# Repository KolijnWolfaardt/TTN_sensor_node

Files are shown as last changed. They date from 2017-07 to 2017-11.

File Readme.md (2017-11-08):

# TTN Sensor Board

This is a basic sensor board I designed to experiment with the LORAWAN protocol, and [The Things Network](https://www.thethingsnetwork.org/) infrastructure. It is by no means intended to be a good or complete example of all the capabilities of either.

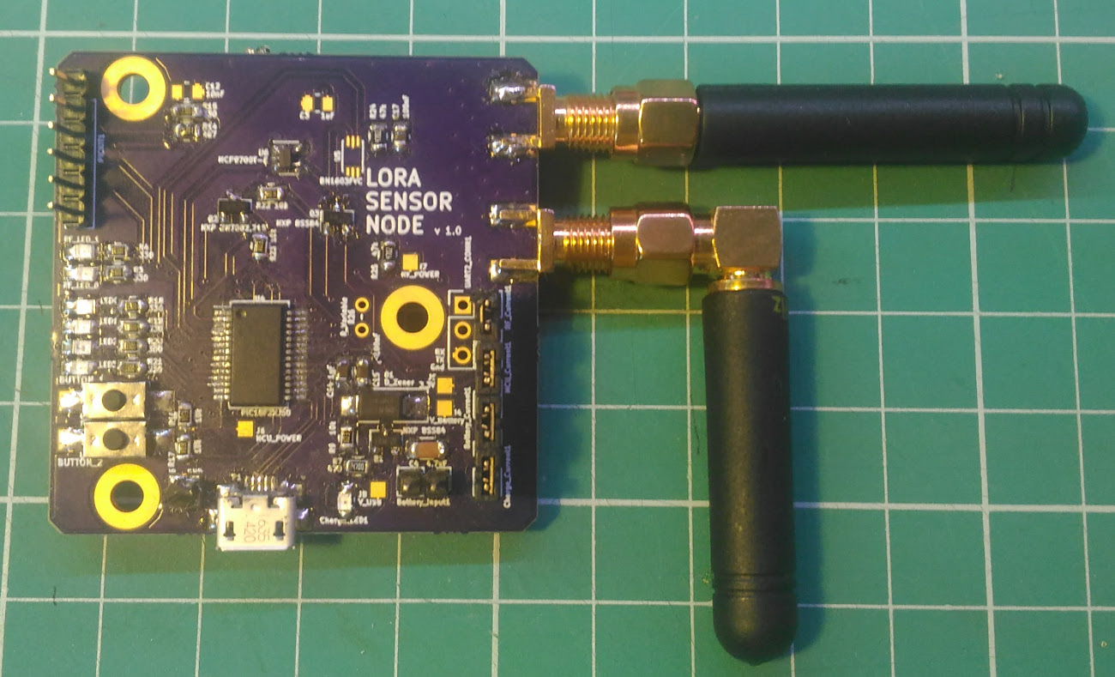
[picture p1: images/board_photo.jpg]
Photo of soldered board


The board uses a Microchip RN2483 to perform the RF communication and a PIC18F46J50 for the other work. The sensors were chosen based on what was available, for experimentation. Other sensors can easily be used.

The board is powered by a single LiPo battery, which is regulated down to 3.3v. To charge the LiPo battery, A MCP73831/2 Battery Management IC is used. The power part is not finished yet, as the batteries have not arrived, so there might be updates here.

## Datasheets
* Microcontroller [PIC18F26J50](http://ww1.microchip.com/downloads/en/DeviceDoc/39931d.pdf)
* Lora Interface module [RN2483](http://ww1.microchip.com/downloads/en/DeviceDoc/50002346A.pdf)
* Battery Management IC [MCP73831/2](http://ww1.microchip.com/downloads/en/DeviceDoc/20001984g.pdf)
* Low dropout Voltage Regulator [TPS736](http://www.ti.com/lit/ds/symlink/tps736.pdf)
* Ambient Light Sensor [BH1603FVC](http://rohmfs.rohm.com/en/products/databook/datasheet/ic/sensor/light/bh1603fvc-e.pdf)
* Thermistor [MCP9701/9701A](http://ww1.microchip.com/downloads/en/DeviceDoc/21942e.pdf)
* P-channel MOSFET [NXP BSS84](http://www.nxp.com/documents/data_sheet/BSS84.pdf)
* N-channel MOSFET [NXP 2N7002](https://www.nxp.com/documents/data_sheet/2N7002.pdf)

Thanks to [https://github.com/jpmeijers/RN2483shield](https://github.com/jpmeijers/RN2483shield) for the RN2483 component and module.

## Schematic and PCB layout
The schematic and PCB layout were created using KiCad, and can be found in the **PCB Layout** folder. The gerber files and schematic PDF can also be found there.

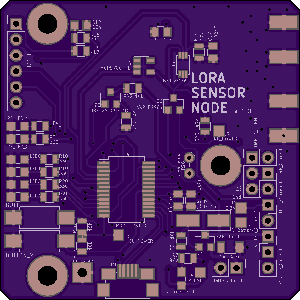
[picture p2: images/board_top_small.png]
Board Top layout
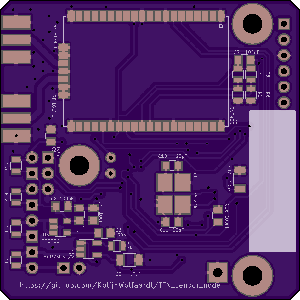
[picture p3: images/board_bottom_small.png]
Board Top layout
  

## Firmware
The firmware can be found in the Firmware folder, and is intended for the [XC8](http://www.microchip.com/mplab/compilers) compiler using the [MPLABX](http://www.microchip.com/mplab/mplab-x-ide) IDE. The board is programmed with a PicKIT 3 programmer, but the PicKIT 2 should also work. The basic flow of the program is shown in basic_control_flow.dia (Open with [http://dia-installer.de/](Dia) flowchart editor) inside the Firmware folder.

[comment]: #  (For more details on the software, see [Firmware/README.md](Firmware/README.md) )

The radio connects via ABP (Activation by personalization). The keys were programmed beforehand using a USB-serial converter, and the radio stores them internally. I will add some code later to set them in the code.

USB stack adapted from [https://github.com/signal11/m-stack.git](https://github.com/signal11/m-stack.git), for its license see the LICENSE file.

[comment]: # (Bill of Materials)

## Board Mistakes
There are two mistakes on the board:
* The ground pin on the PicKit header is not connected.
* The battery voltage measurement circuit does not work. I replaced it with a voltage divider.

These are suggestions that require more rework, but are only for ease of use.
* I cannot identify pin 1 of the optical sensor, so I left it off.
* Breaking out the TX and RX lines to the RF module would have eased debugging.
* A reset button would be nice, resetting both the MCU and the RF module.

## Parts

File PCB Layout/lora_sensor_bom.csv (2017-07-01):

Reference | Quantity | Value | Footprint | Datasheet
BUTTON_1 BUTTON_2 | 2 | SwitchTactile | Buttons_Switches_SMD:SW_SPST_REED_CT05-XXXX-G1
C1 C15 C16 C17 C2 C6 C7 C8 | 8 | 100nF | Capacitors_SMD:C_0805
C10 C11 | 2 | 22pF | Capacitors_SMD:C_0805
C12 | 1 | 10nF | Capacitors_SMD:C_0805
C13 | 1 | 10uF | Capacitors_SMD:C_1206
C14 C3 C9 | 3 | 1uF | Capacitors_SMD:C_0805
C4 C5 | 2 | 4.7uF | Capacitors_SMD:C_1206
D1 | 1 | D_Zener | Diodes_SMD:D_SMA_Handsoldering
J1 J2 J3 | 3 | CONN_01X01 | Mounting_Holes:MountingHole_3.2mm_M3_Pad
J4 | 1 | V_Battery | Measurement_Points:Measurement_Point_Square-SMD-Pad_Small
J5 | 1 | 3.3V | Measurement_Points:Measurement_Point_Square-SMD-Pad_Small
J6 | 1 | MCU_POWER | Measurement_Points:Measurement_Point_Square-SMD-Pad_Small
J7 | 1 | RF_POWER | Measurement_Points:Measurement_Point_Square-SMD-Pad_Small
J8 | 1 | V_USB | Measurement_Points:Measurement_Point_Square-SMD-Pad_Small
J9 | 1 | GND | Measurement_Points:Measurement_Point_Square-TH_Big
Battery_Current1 Battery_Input1 Charge_Current1 MCU_Current1 RF_Current1 | 5 | CONN_01X02 | Pin_Headers:Pin_Header_Straight_1x02_Pitch2.54mm
P1 | 1 | USB_A | libraries:USB_Micro
PICKIT1 | 1 | CONN_01X06 | Pin_Headers:Pin_Header_Straight_1x06_Pitch2.54mm
Q1 Q3 | 2 | NXP BSS84 | TO_SOT_Packages_SMD:SOT-23
Q2 | 1 | NXP 2N7002,215 | TO_SOT_Packages_SMD:SOT-23
R10 | 1 | 2k | Resistors_SMD:R_0805
R14 | 1 | 4k7 | Resistors_SMD:R_0805
R24 R25 | 2 | 47k | Resistors_SMD:R_0805
R26 | 1 | R_Variable | Resistors_ThroughHole:R_Axial_DIN0204_L3.6mm_D1.6mm_P2.54mm_Vertical
R15 R18 R19 R20 R21 R3 R4 | 7 | 330 | Resistors_SMD:R_0805
R1 R11 R12 R13 R2 R5 R6 R8 | 8 | 0 | Resistors_SMD:R_0805
R7 | 1 | 470 | Resistors_SMD:R_0805
R16 R17 R22 R23 R9 | 5 | 10k | Resistors_SMD:R_0805
RF_HIGH_1 RF_LOW_1 | 2 | CONN_01X02 | libraries:SMA_edge_connect
LED0 LED1 LED2 LED3 Power_LED1 RF_LED_0 RF_LED_1 | 7 | LED | LEDs:LED_0805
U1 | 1 | RN2483 | libraries:RN2483
U2 | 1 | MCP73831/2 | TO_SOT_Packages_SMD:TSOT-23-5
U3 | 1 | TPS736 | TO_SOT_Packages_SMD:SOT-23-5
U4 | 1 | PIC18F2XJ50 | Housings_SSOP:SSOP-28_5.3x10.2mm_Pitch0.65mm
U5 | 1 | BH1603FVC | libraries:BH1603FVC
U6 | 1 | MCP9700T-E | TO_SOT_Packages_SMD:SOT-23-5
UART2_CONN1 | 1 | CONN_01X03 | Pin_Headers:Pin_Header_Straight_1x03_Pitch2.54mm
Y1 | 1 | FA_238 | libraries:Crystal_FA-238

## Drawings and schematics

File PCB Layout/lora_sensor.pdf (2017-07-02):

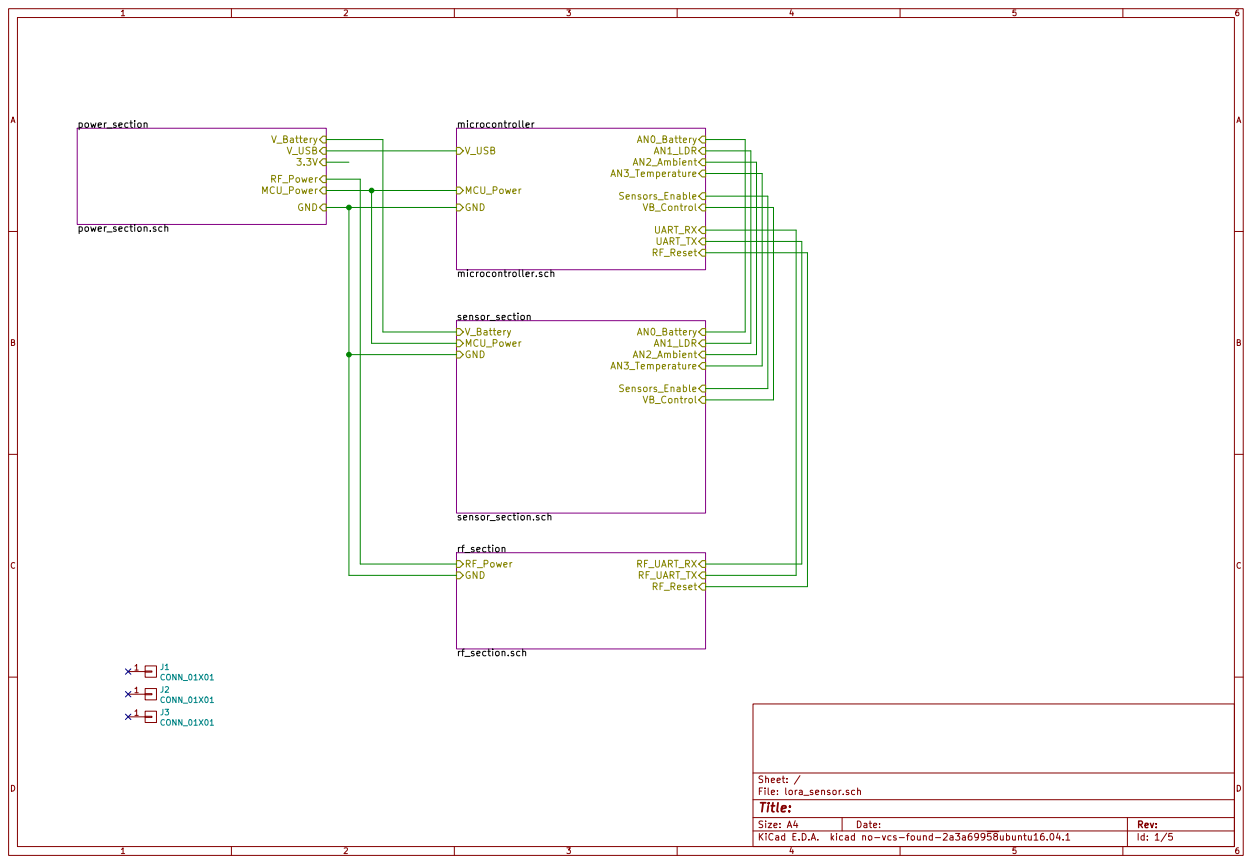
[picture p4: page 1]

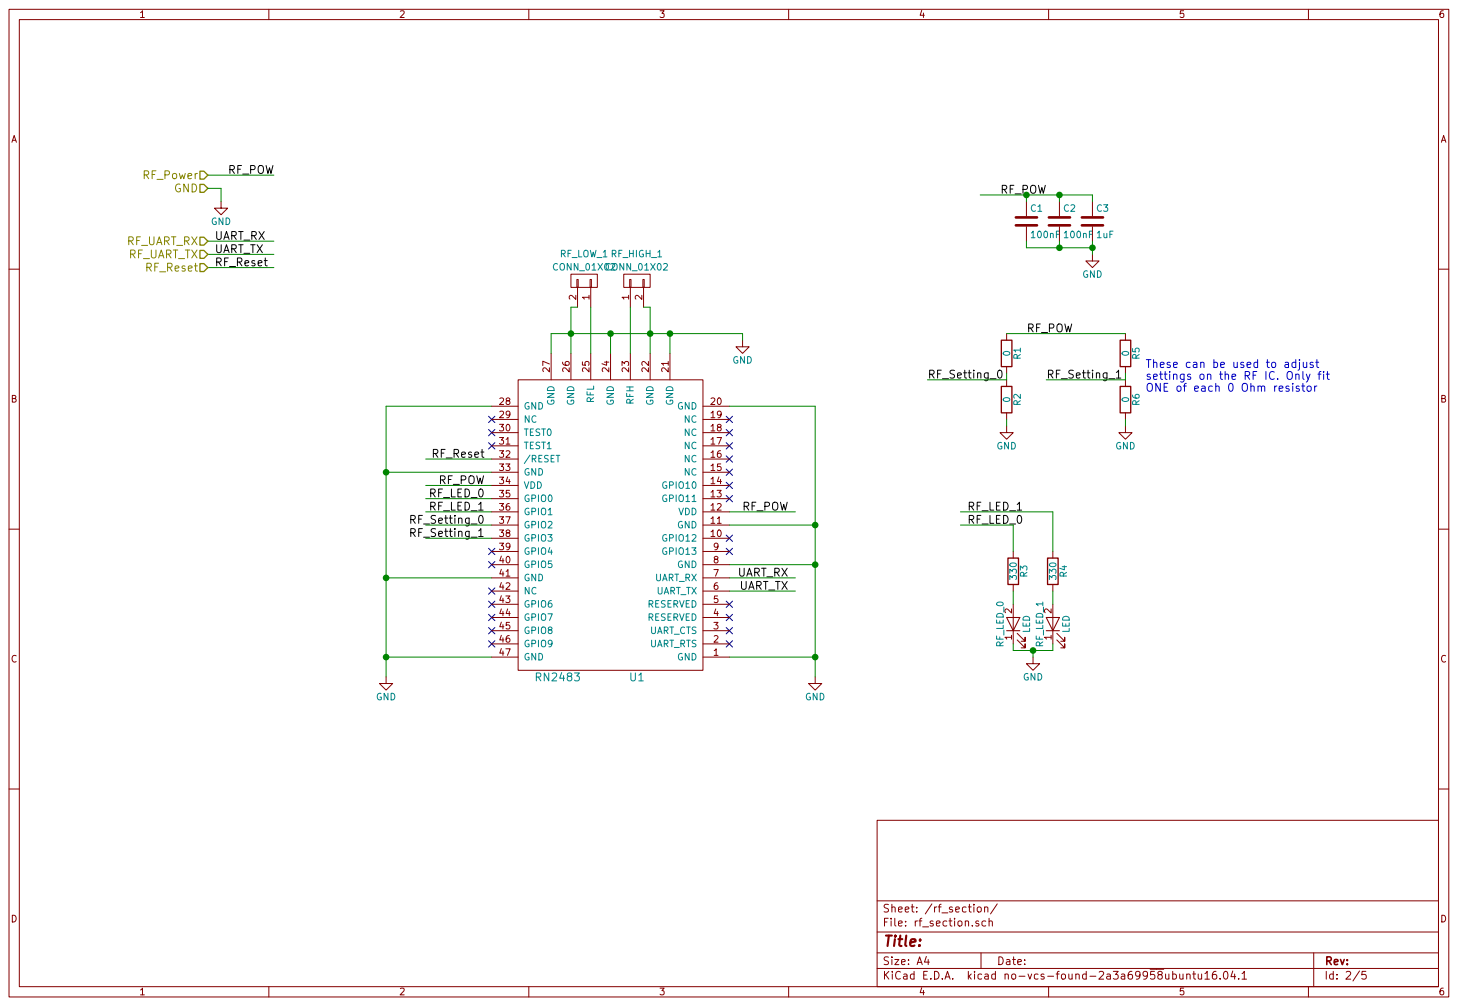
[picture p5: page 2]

These can be used to adjust
settings on the RF IC. Only fit
ONE of each 0 Ohm resistor

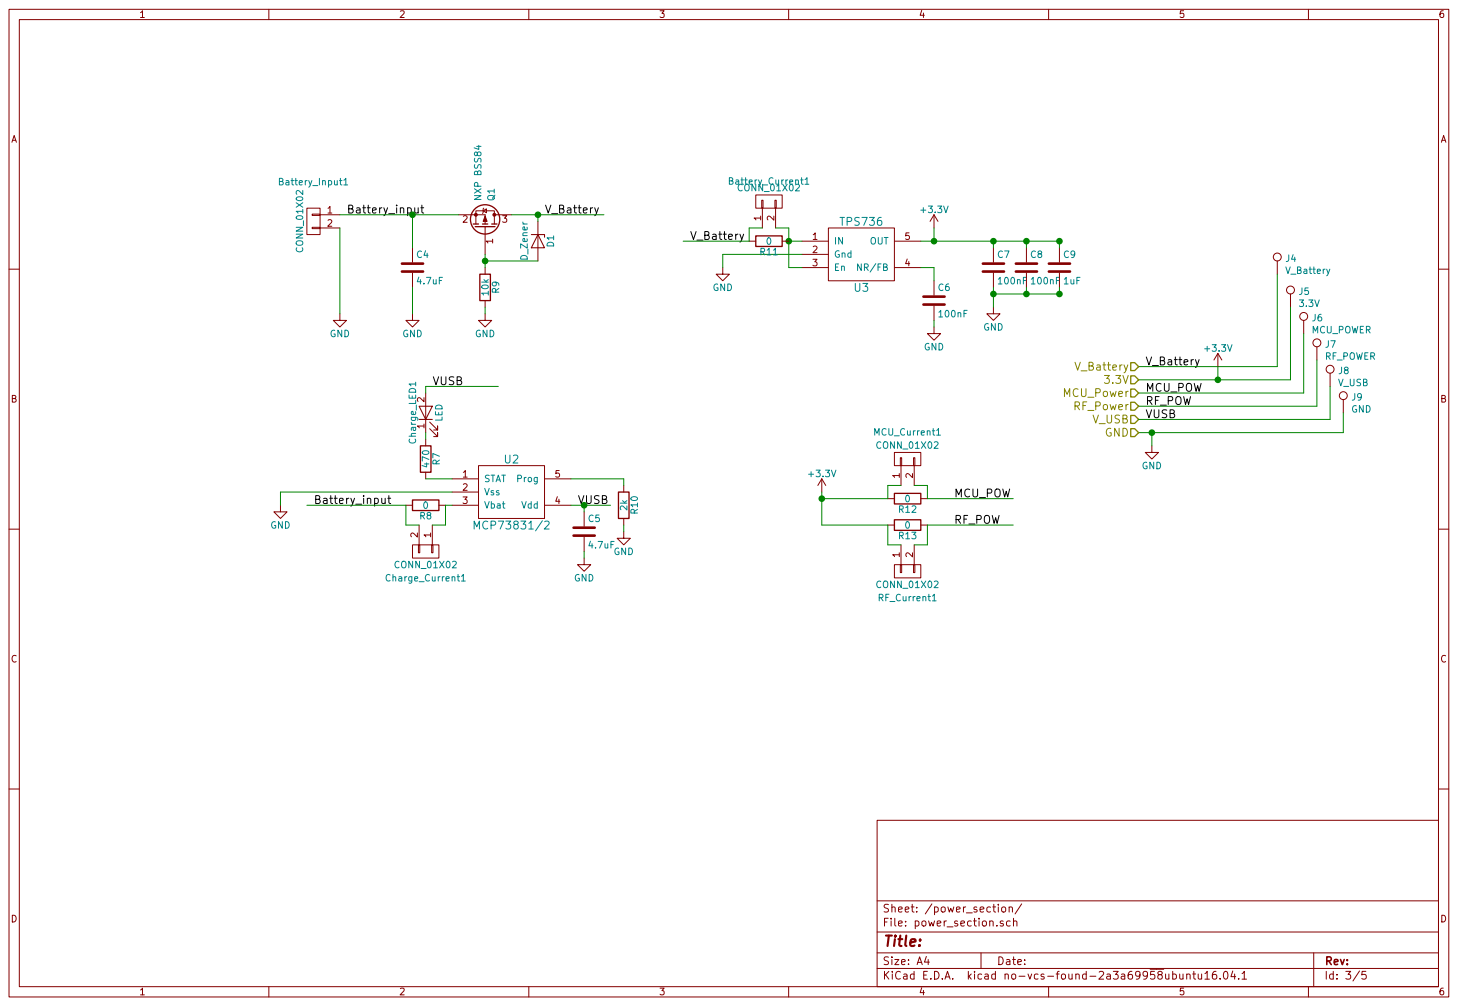
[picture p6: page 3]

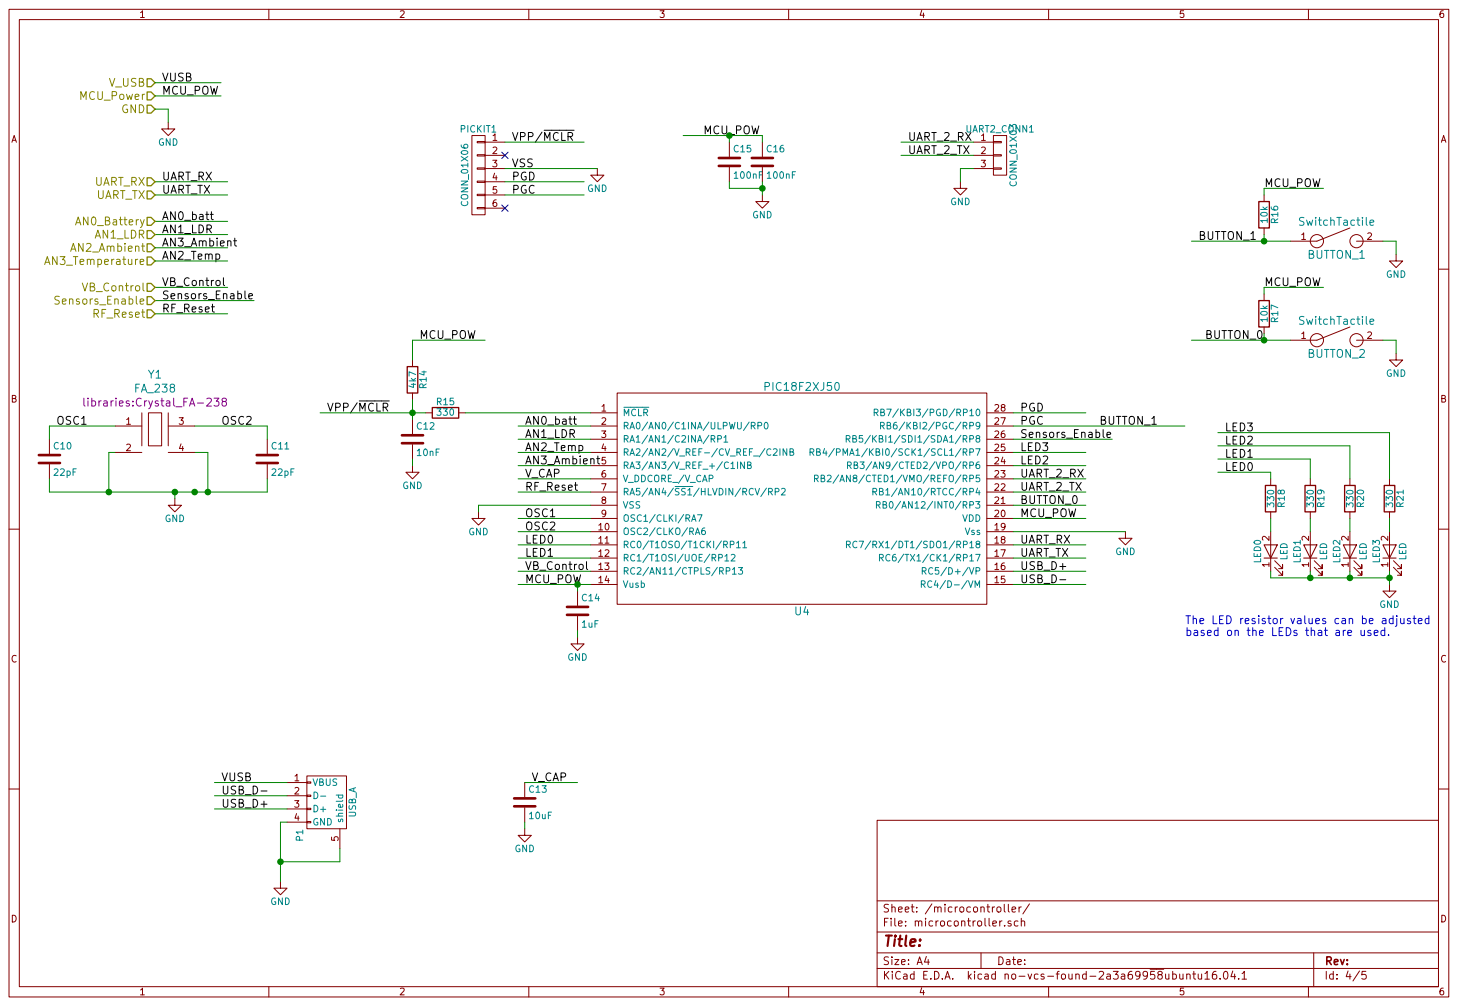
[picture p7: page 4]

The LED resistor values can be adjusted based on the LEDs that are used. AN3_Ambient
AN2_Temp

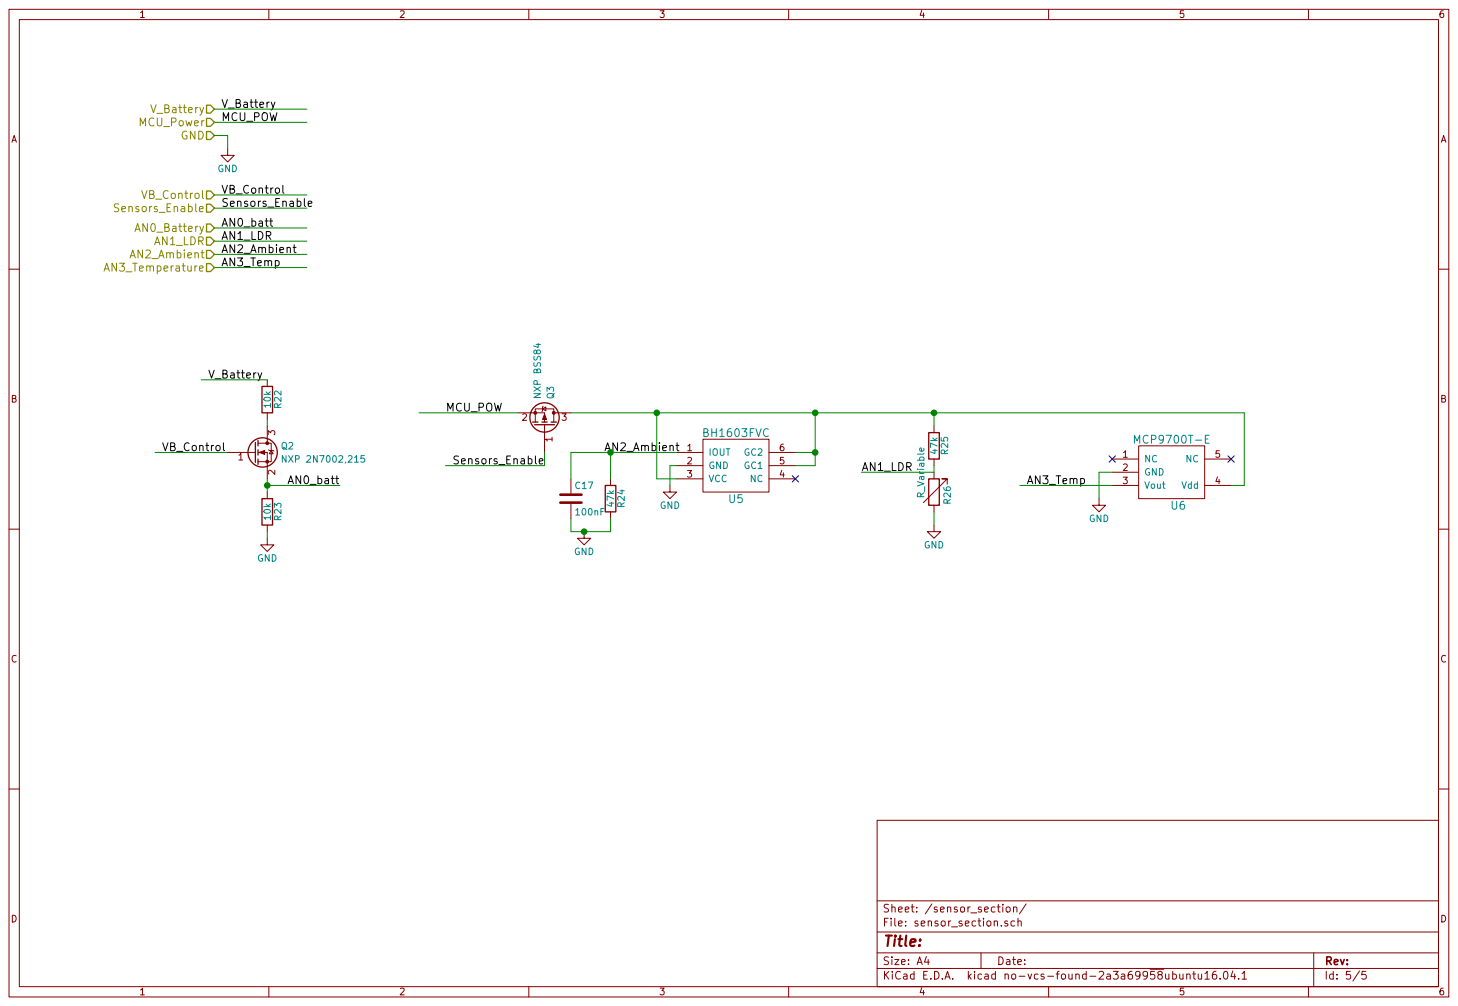
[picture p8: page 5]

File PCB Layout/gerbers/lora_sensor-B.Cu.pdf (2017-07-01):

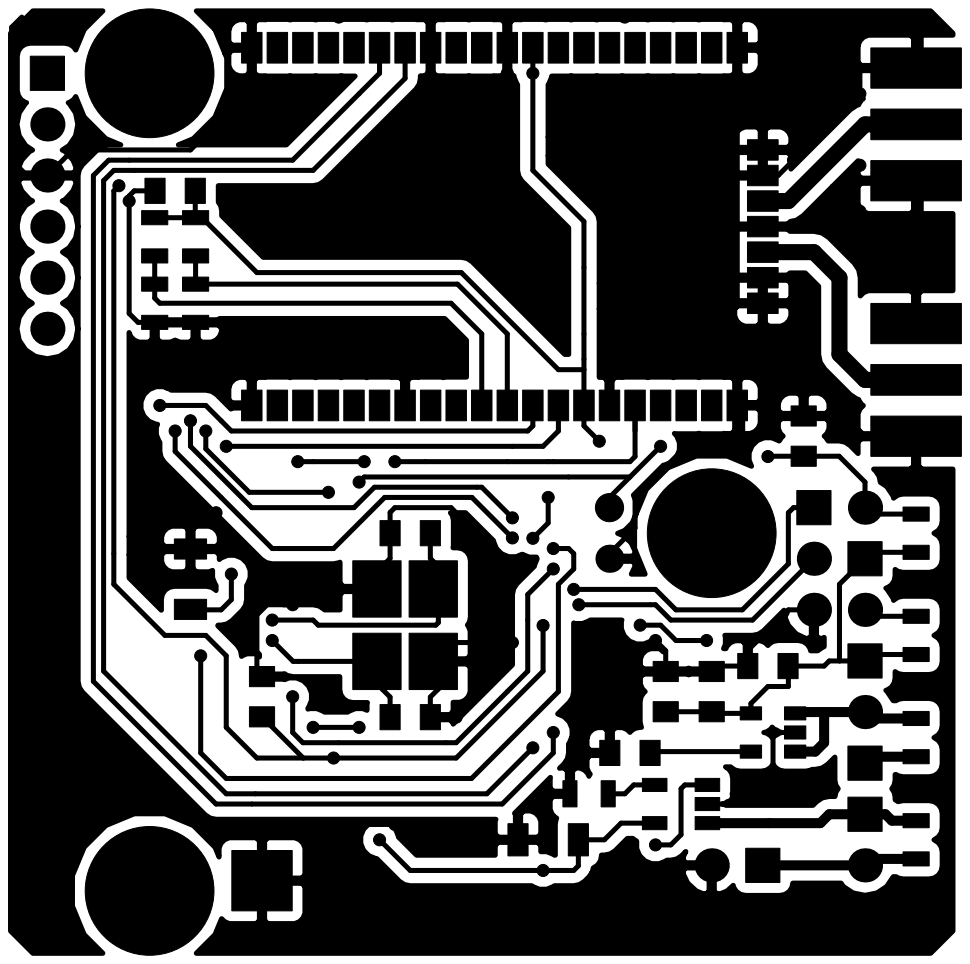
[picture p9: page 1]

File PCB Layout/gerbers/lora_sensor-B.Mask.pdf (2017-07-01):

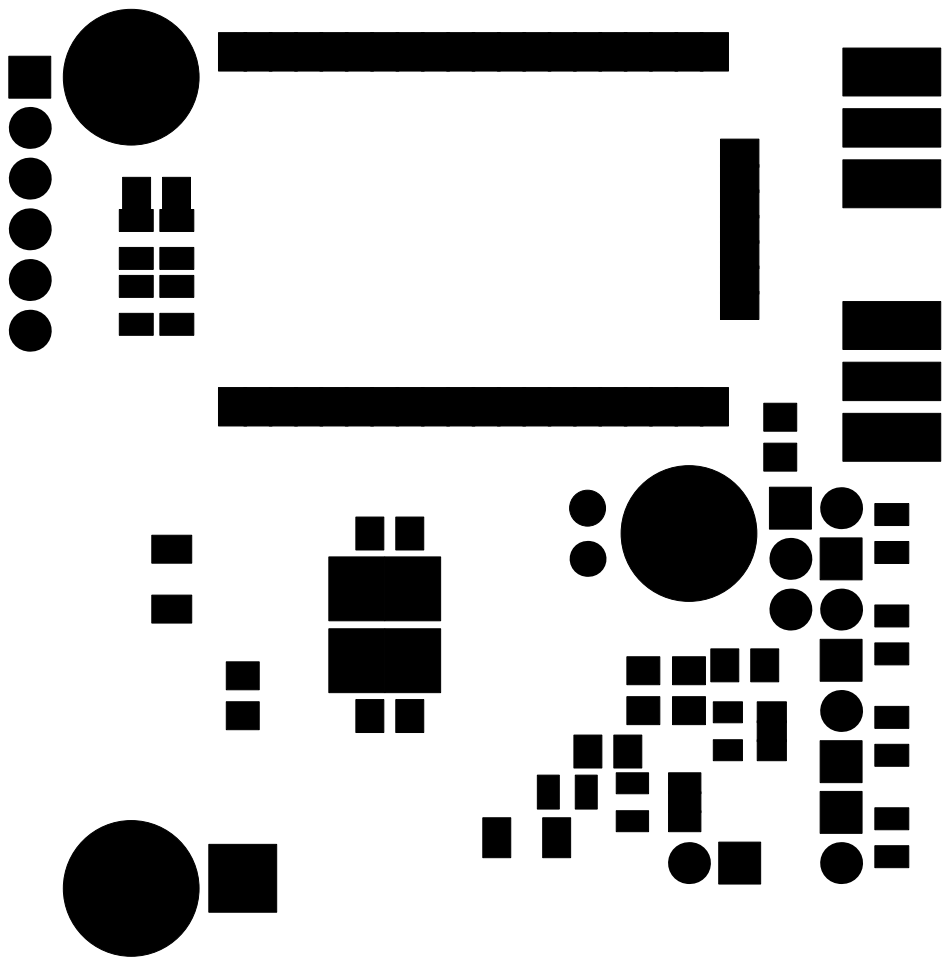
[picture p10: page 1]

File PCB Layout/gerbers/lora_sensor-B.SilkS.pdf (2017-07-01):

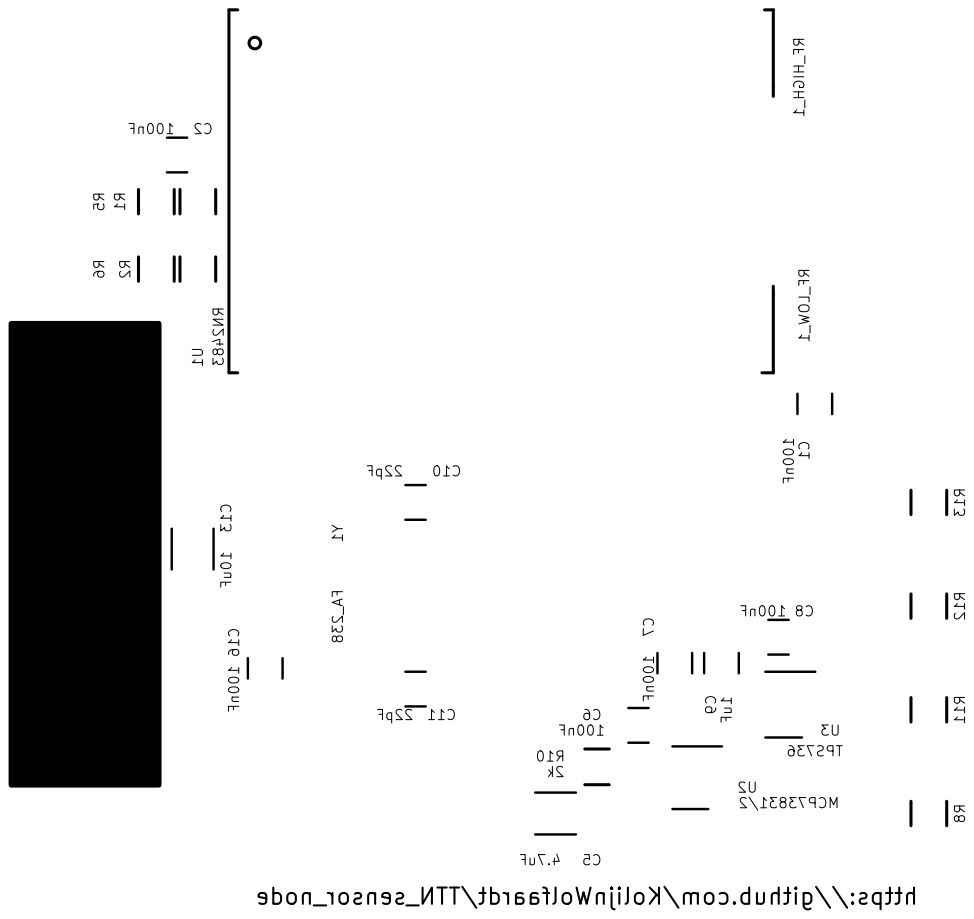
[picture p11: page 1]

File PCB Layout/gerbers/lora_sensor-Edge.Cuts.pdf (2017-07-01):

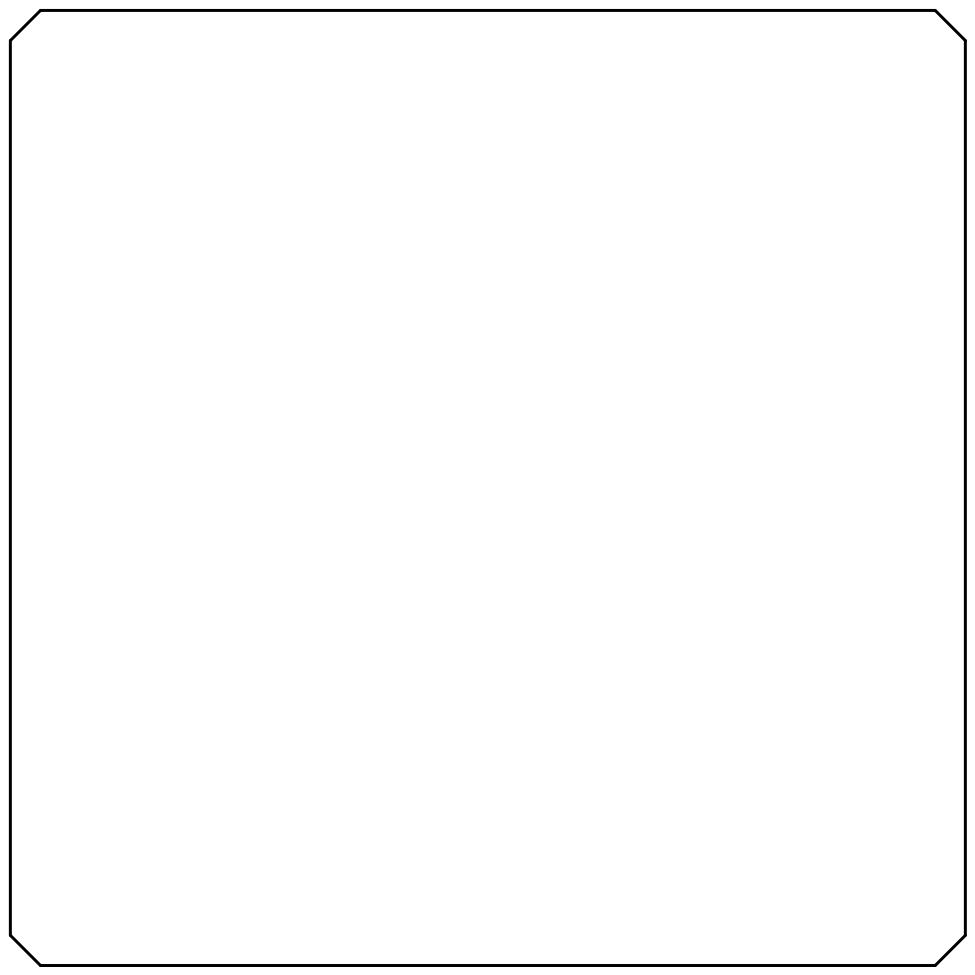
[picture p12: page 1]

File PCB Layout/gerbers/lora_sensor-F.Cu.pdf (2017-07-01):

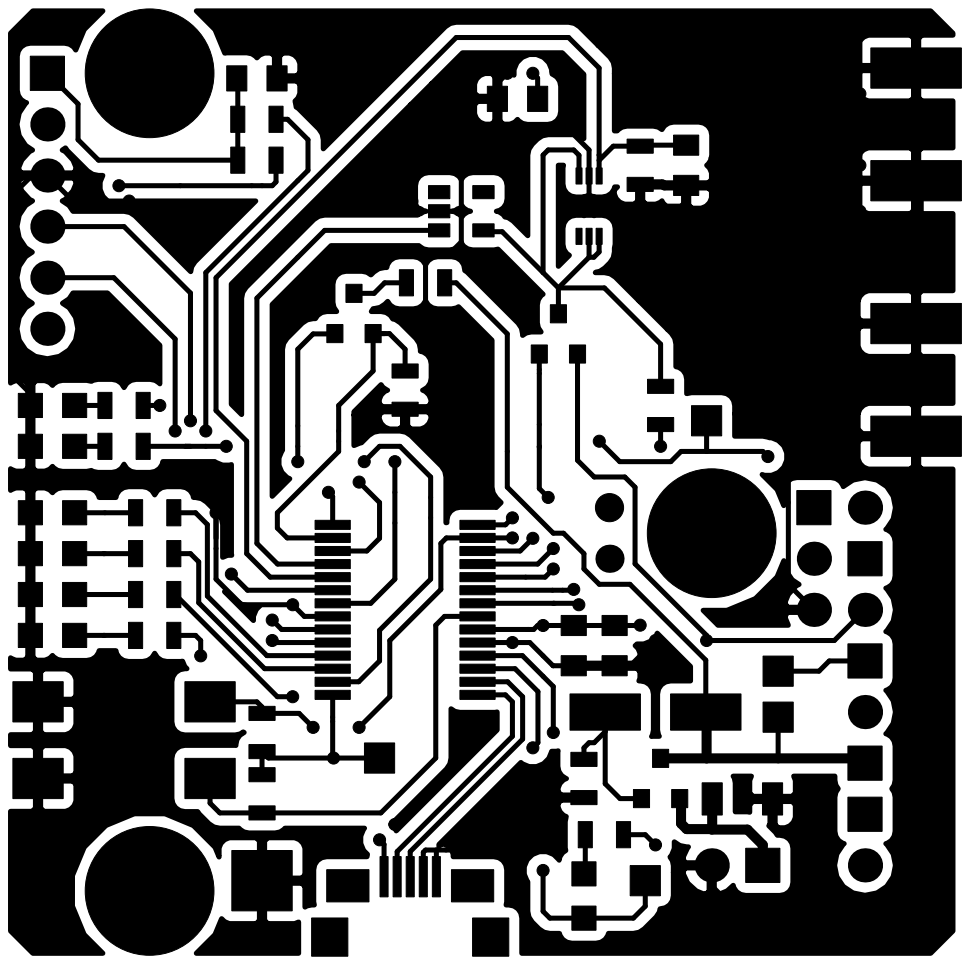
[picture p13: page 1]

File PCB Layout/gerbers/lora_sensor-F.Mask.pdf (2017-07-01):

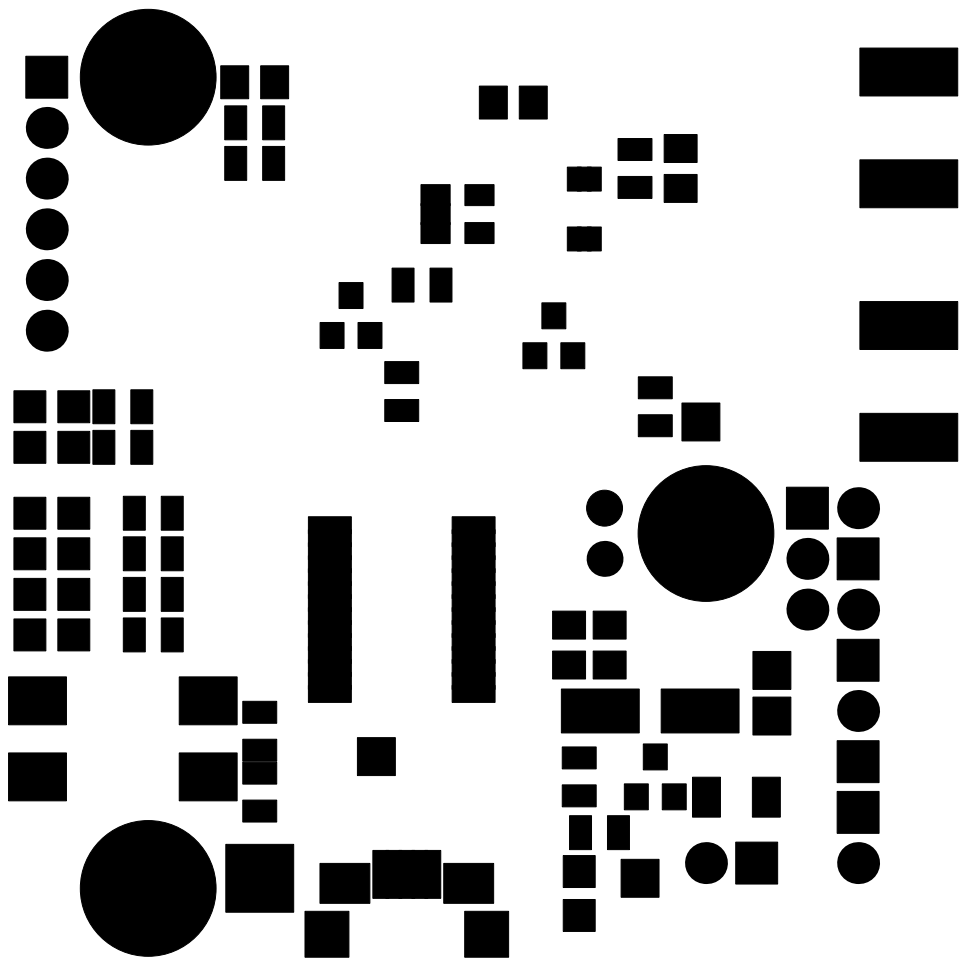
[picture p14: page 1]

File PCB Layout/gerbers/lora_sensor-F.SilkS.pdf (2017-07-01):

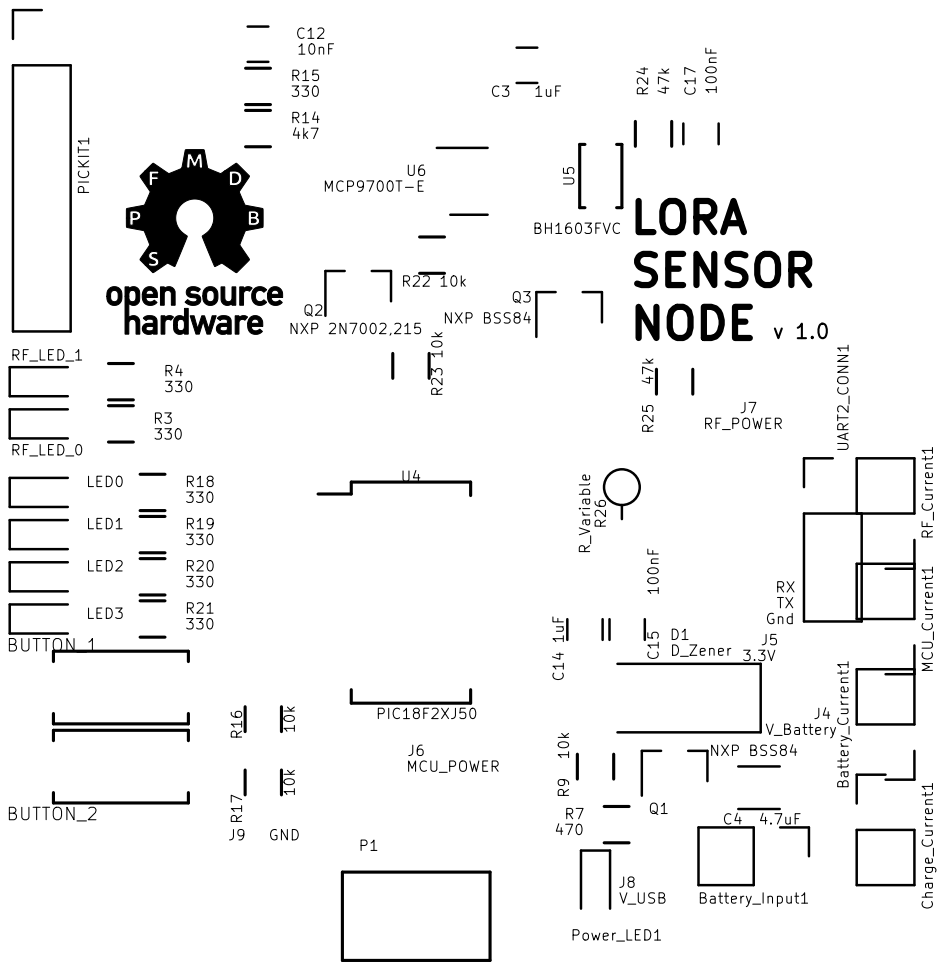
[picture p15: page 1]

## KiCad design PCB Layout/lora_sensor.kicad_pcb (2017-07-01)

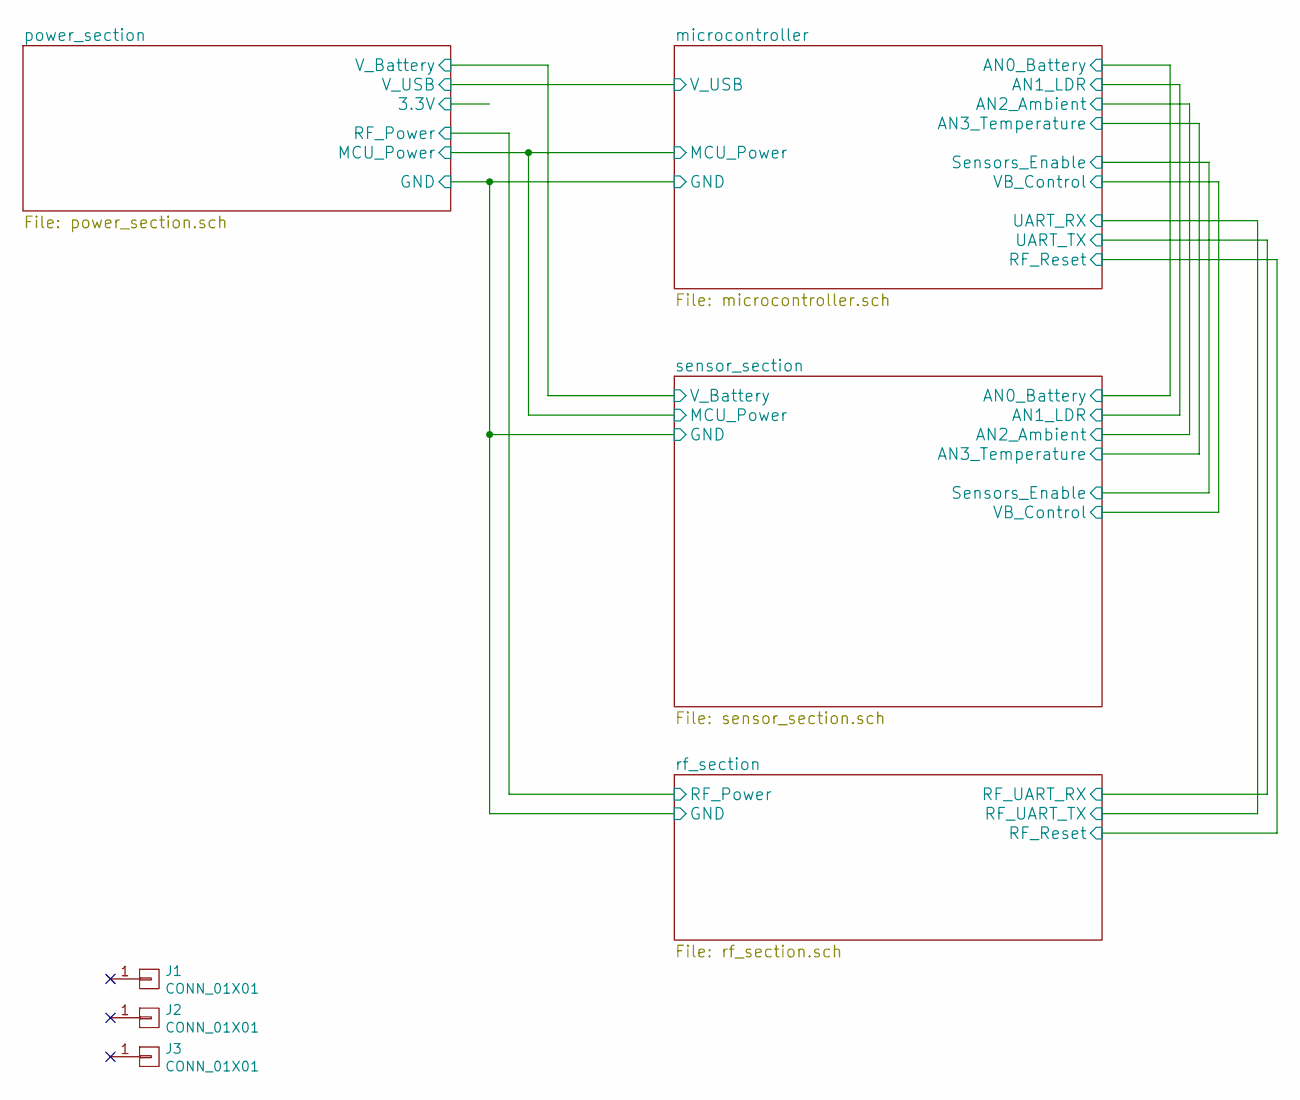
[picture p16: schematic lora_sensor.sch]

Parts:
J1, J2, J3: CONN_01X01; MountingHole_3.2mm_M3_Pad

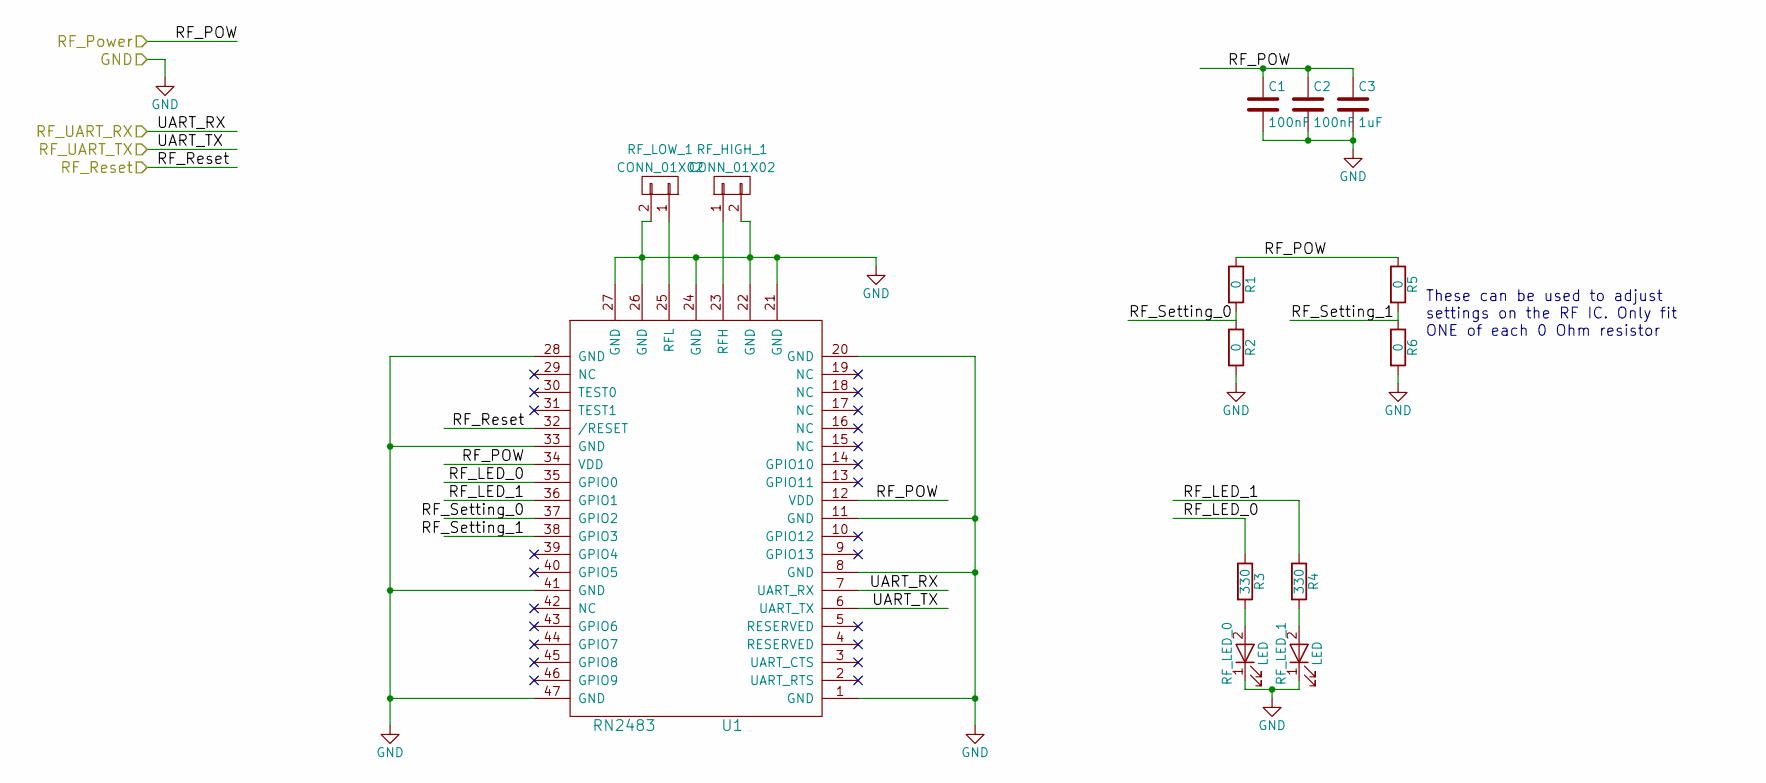
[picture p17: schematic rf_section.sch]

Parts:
C1, C2: 100nF; C_0805
C3: 1uF; C_0805
R1, R2, R5, R6: 0; R_0805
R3, R4: 330; R_0805
RF_HIGH_1: CONN_01X02; SMA_edge_connect
RF_LED_0, RF_LED_1: LED; LED_0805
RF_LOW_1: CONN_01X02; SMA_edge_connect
U1: RN2483

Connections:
/microcontroller/RF_Reset: U1.32 (/RESET); also elsewhere on the board
/power_section/RF_Power: C1.1, C2.1, C3.1, R1.1, R5.1, U1.12 (VDD), U1.34 (VDD); also elsewhere on the board
/rf_section/RF_LED_0: R3.1, U1.35 (GPIO0)
/rf_section/RF_LED_1: R4.1, U1.36 (GPIO1)
/rf_section/RF_Setting_0: R1.2, R2.1, U1.37 (GPIO2)
/rf_section/RF_Setting_1: R5.2, R6.1, U1.38 (GPIO3)
/rf_section/RF_UART_RX: U1.7 (UART_RX); also elsewhere on the board
/rf_section/RF_UART_TX: U1.6 (UART_TX); also elsewhere on the board
GND: C1.2, C2.2, C3.2, R2.2, R6.2, RF_HIGH_1.2, RF_LED_0.1 (K), RF_LED_1.1 (K), RF_LOW_1.2, U1.1 (GND), U1.8 (GND), U1.11 (GND), U1.20 (GND), U1.21 (GND), U1.22 (GND), U1.24 (GND), U1.26 (GND), U1.27 (GND), U1.28 (GND), U1.33 (GND), U1.41 (GND), U1.47 (GND); also elsewhere on the board
unnamed: R3.2, RF_LED_0.2 (A)
unnamed: R4.2, RF_LED_1.2 (A)
unnamed: RF_HIGH_1.1, U1.23 (RFH)
unnamed: RF_LOW_1.1, U1.25 (RFL)

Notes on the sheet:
These can be used to adjust settings on the RF IC. Only fit ONE of each 0 Ohm resistor

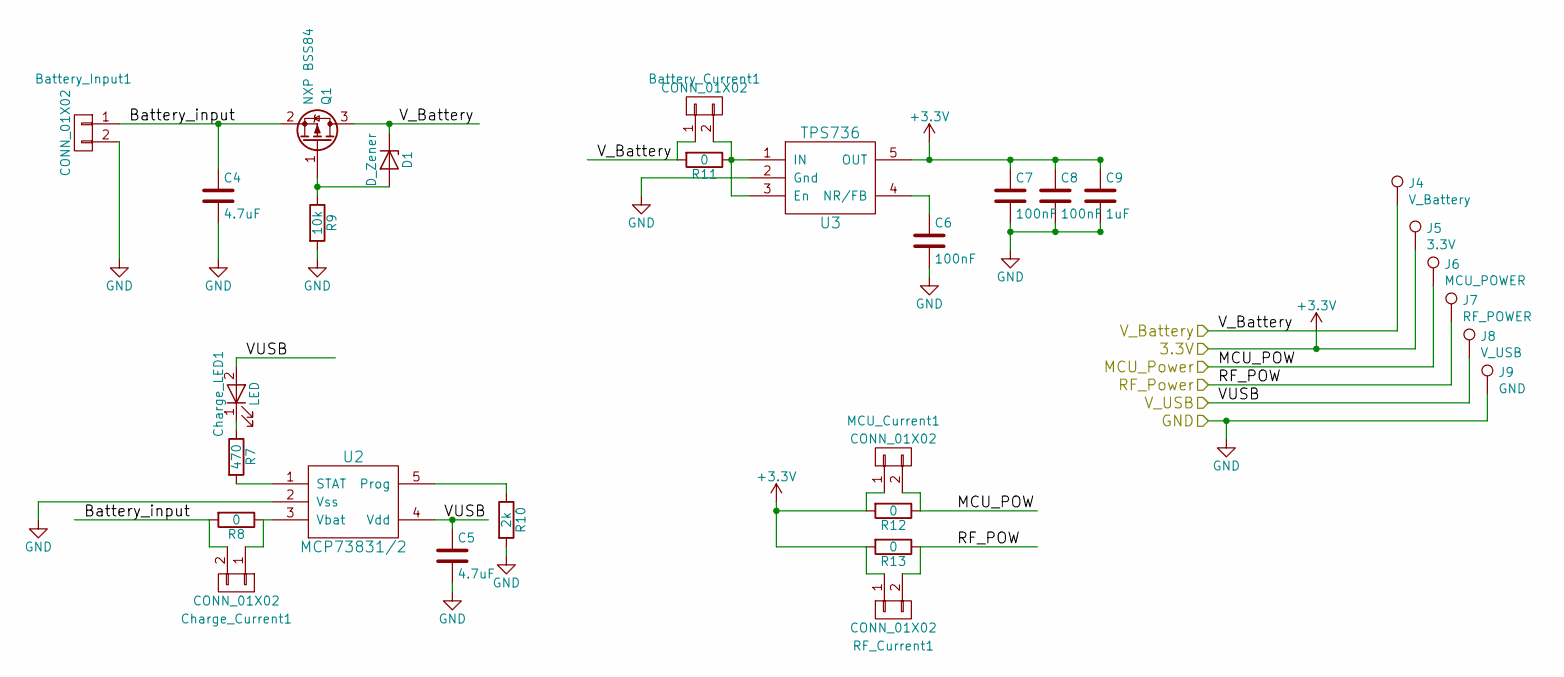
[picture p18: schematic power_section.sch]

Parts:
Battery_Current1: CONN_01X02; Pin_Header_Straight_1x02_Pitch2.54mm
Battery_Input1: CONN_01X02; Pin_Header_Straight_1x02_Pitch2.54mm
C4, C5: 4.7uF; C_1206
C6, C7, C8: 100nF; C_0805
C9: 1uF; C_0805
Charge_Current1: CONN_01X02; Pin_Header_Straight_1x02_Pitch2.54mm
D1: D_Zener; D_SMA_Handsoldering
J4: V_Battery; Measurement_Point_Square-SMD-Pad_Small
J5: 3.3V; Measurement_Point_Square-SMD-Pad_Small
J6: MCU_POWER; Measurement_Point_Square-SMD-Pad_Small
J7: RF_POWER; Measurement_Point_Square-SMD-Pad_Small
J8: V_USB; Measurement_Point_Square-SMD-Pad_Small
J9: GND; Measurement_Point_Square-TH_Big
MCU_Current1: CONN_01X02; Pin_Header_Straight_1x02_Pitch2.54mm
Power_LED1: LED; LED_0805
Q1: NXP BSS84; SOT-23
R7: 470; R_0805
R8, R11, R12, R13: 0; R_0805
R9: 10k; R_0805
R10: 2k; R_0805
RF_Current1: CONN_01X02; Pin_Header_Straight_1x02_Pitch2.54mm
U2: MCP73831/2; TSOT-23-5
U3: TPS736; SOT-23-5

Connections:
/microcontroller/MCU_Power: J6.1, MCU_Current1.2, R12.1; also elsewhere on the board
/microcontroller/V_USB: C5.1, J8.1, U2.4 (Vdd); also elsewhere on the board
/power_section/Battery_input: Battery_Input1.1, C4.1, Charge_Current1.2, Q1.2 (S), R8.2
/power_section/RF_Power: J7.1, R13.1, RF_Current1.2; also elsewhere on the board
GND: Battery_Input1.2, C4.2, C5.2, C6.2, C7.2, C8.2, C9.2, J9.1, R9.2, R10.2, U2.2 (Vss), U3.2 (Gnd); also elsewhere on the board
unnamed: Battery_Current1.2, R11.1, U3.1 (IN), U3.3 (En)
unnamed: C6.1, U3.4 (NR/FB)
unnamed: Charge_Current1.1, R8.1, U2.3 (Vbat)
unnamed 36: R7.1; also elsewhere on the board
unnamed: D1.2 (A), Q1.1 (G), R9.1
unnamed: R7.2, U2.1 (STAT)
unnamed: R10.1, U2.5 (Prog)

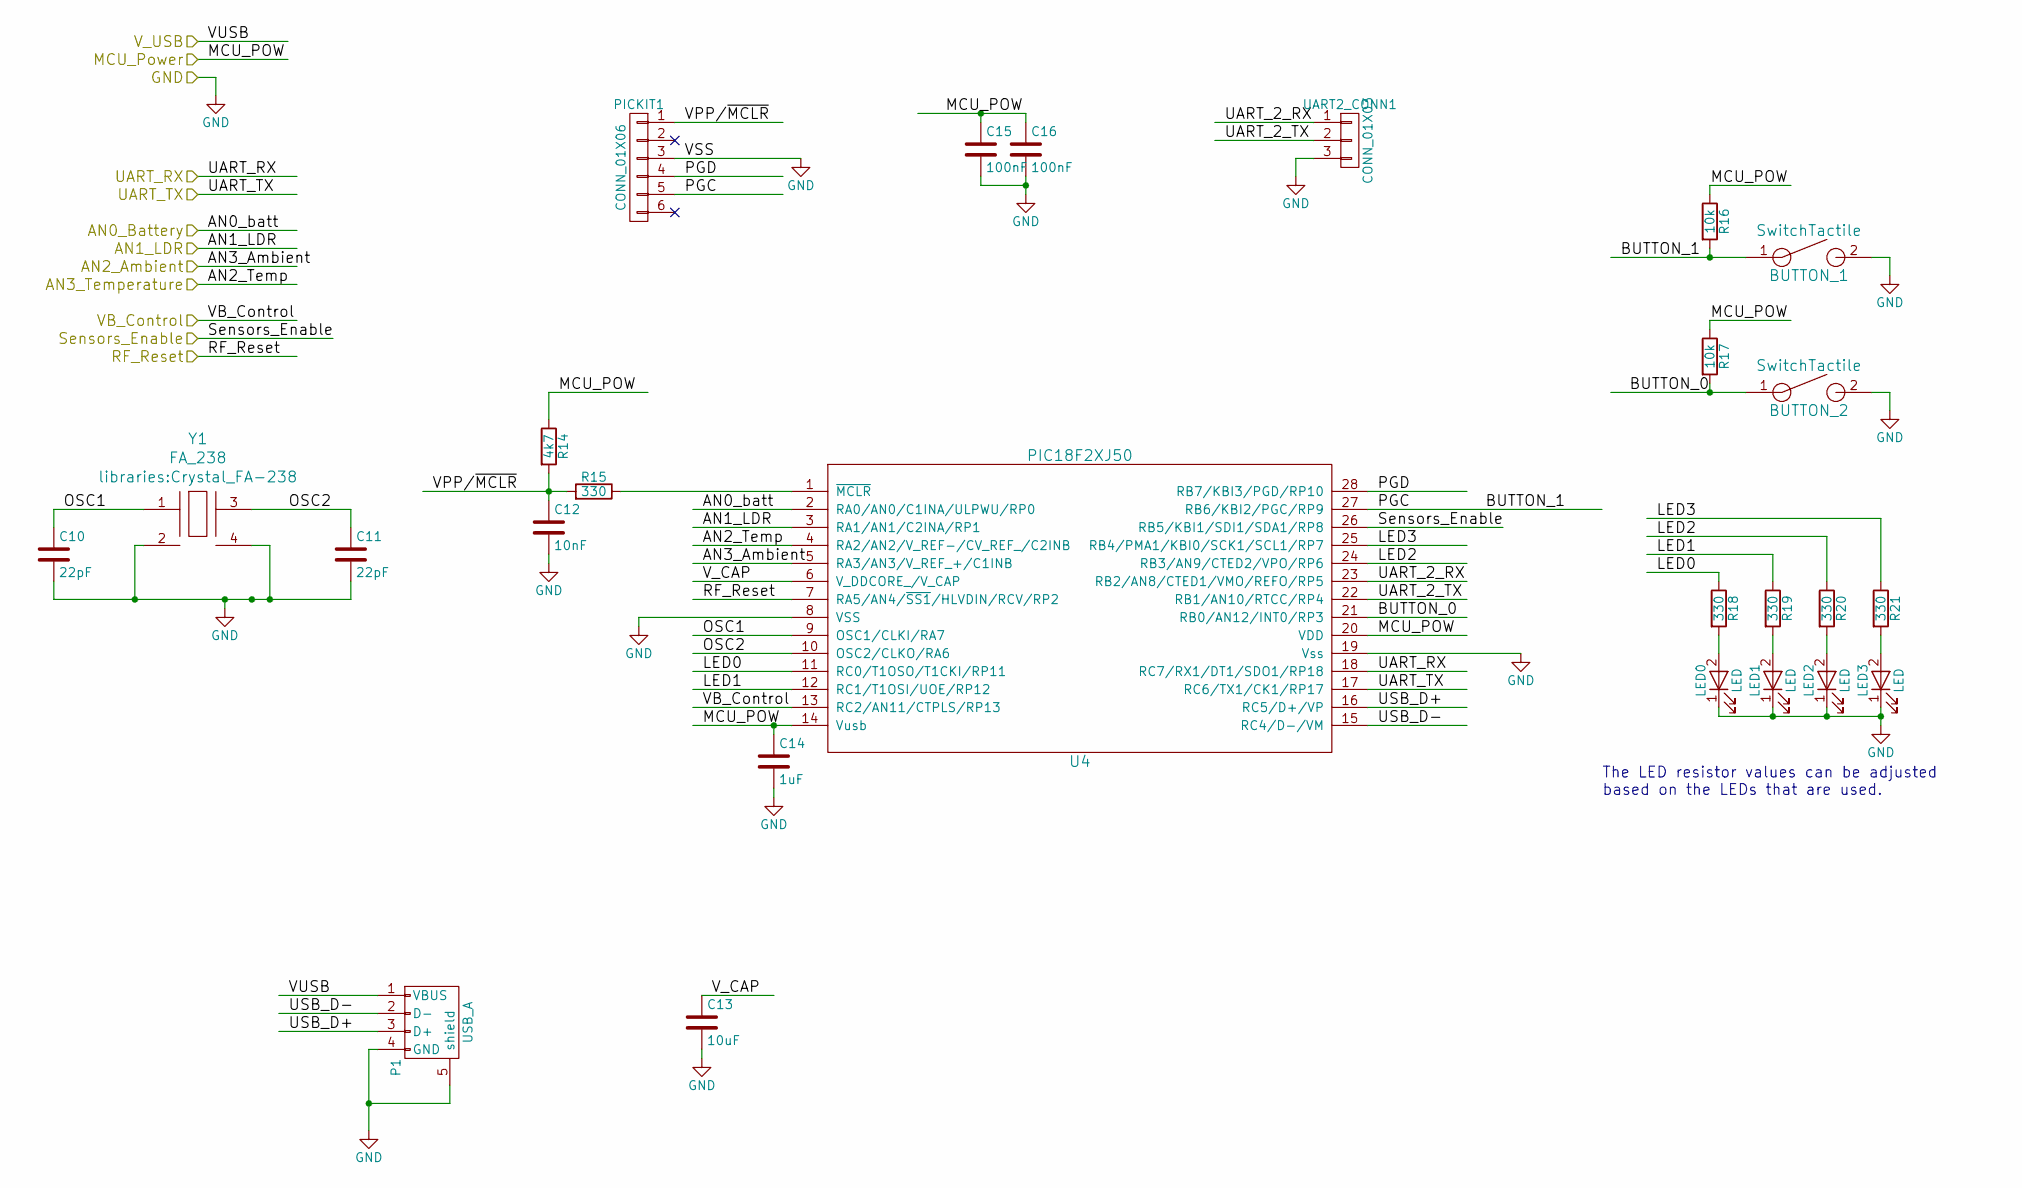
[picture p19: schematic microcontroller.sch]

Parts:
BUTTON_1, BUTTON_2: SwitchTactile; SW_SPST_REED_CT05-XXXX-G1
C10, C11: 22pF; C_0805
C12: 10nF; C_0805
C13: 10uF; C_1206
C14: 1uF; C_0805
C15, C16: 100nF; C_0805
LED0, LED1, LED2, LED3: LED; LED_0805
P1: USB_A; USB_Micro
PICKIT1: CONN_01X06; Pin_Header_Straight_1x06_Pitch2.54mm
R14: 4k7; R_0805
R15, R18, R19, R20, R21: 330; R_0805
R16, R17: 10k; R_0805
U4: PIC18F2XJ50; SSOP-28_5.3x10.2mm_Pitch0.65mm
UART2_CONN1: CONN_01X03; Pin_Header_Straight_1x03_Pitch2.54mm
Y1: FA_238; Crystal_FA-238

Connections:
/microcontroller/AN0_Battery: U4.2 (RA0/AN0/C1INA/ULPWU/RP0); also elsewhere on the board
/microcontroller/AN1_LDR: U4.3 (RA1/AN1/C2INA/RP1); also elsewhere on the board
/microcontroller/AN2_Ambient: U4.5 (RA3/AN3/V_REF_+/C1INB); also elsewhere on the board
/microcontroller/AN3_Temperature: U4.4 (RA2/AN2/V_REF-/CV_REF_/C2INB); also elsewhere on the board
/microcontroller/BUTTON_0: BUTTON_2.1, R17.2, U4.21 (RB0/AN12/INT0/RP3)
/microcontroller/BUTTON_1: BUTTON_1.1, PICKIT1.5, R16.2, U4.27 (RB6/KBI2/PGC/RP9)
/microcontroller/LED0: R18.1, U4.11 (RC0/T1OSO/T1CKI/RP11)
/microcontroller/LED1: R19.1, U4.12 (RC1/T1OSI/UOE/RP12)
/microcontroller/LED2: R20.1, U4.24 (RB3/AN9/CTED2/VPO/RP6)
/microcontroller/LED3: R21.1, U4.25 (RB4/PMA1/KBI0/SCK1/SCL1/RP7)
/microcontroller/MCU_Power: C14.1, C15.1, C16.1, R14.1, R16.1, R17.1, U4.14 (Vusb), U4.20 (VDD); also elsewhere on the board
/microcontroller/OSC1: C10.1, U4.9 (OSC1/CLKI/RA7), Y1.1
/microcontroller/OSC2: C11.1, U4.10 (OSC2/CLKO/RA6), Y1.3
/microcontroller/PGD: PICKIT1.4, U4.28 (RB7/KBI3/PGD/RP10)
/microcontroller/RF_Reset: U4.7 (RA5/AN4/~SS1~/HLVDIN/RCV/RP2); also elsewhere on the board
/microcontroller/Sensors_Enable: U4.26 (RB5/KBI1/SDI1/SDA1/RP8); also elsewhere on the board
/microcontroller/UART_2_RX: U4.23 (RB2/AN8/CTED1/VMO/REFO/RP5), UART2_CONN1.1
/microcontroller/UART_2_TX: U4.22 (RB1/AN10/RTCC/RP4), UART2_CONN1.2
/microcontroller/USB_D+: P1.3 (D+), U4.16 (RC5/D+/VP)
/microcontroller/USB_D-: P1.2 (D-), U4.15 (RC4/D-/VM)
/microcontroller/VB_Control: U4.13 (RC2/AN11/CTPLS/RP13); also elsewhere on the board
/microcontroller/VPP/~MCLR: C12.1, PICKIT1.1, R14.2, R15.2
/microcontroller/V_CAP: C13.1, U4.6 (V_DDCORE_/V_CAP)
/microcontroller/V_USB: P1.1 (VBUS); also elsewhere on the board
/rf_section/RF_UART_RX: U4.17 (RC6/TX1/CK1/RP17); also elsewhere on the board
/rf_section/RF_UART_TX: U4.18 (RC7/RX1/DT1/SDO1/RP18); also elsewhere on the board
GND: BUTTON_1.2, BUTTON_2.2, C10.2, C11.2, C12.2, C13.2, C14.2, C15.2, C16.2, LED0.1 (K), LED1.1 (K), LED2.1 (K), LED3.1 (K), P1.4 (GND), P1.5 (shield), PICKIT1.3, U4.8 (VSS), U4.19 (Vss), UART2_CONN1.3, Y1.2, Y1.4; also elsewhere on the board
unnamed: LED0.2 (A), R18.2
unnamed: LED1.2 (A), R19.2
unnamed: LED2.2 (A), R20.2
unnamed: LED3.2 (A), R21.2
unnamed: R15.1, U4.1 (~MCLR)

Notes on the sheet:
The LED resistor values can be adjusted based on the LEDs that are used.

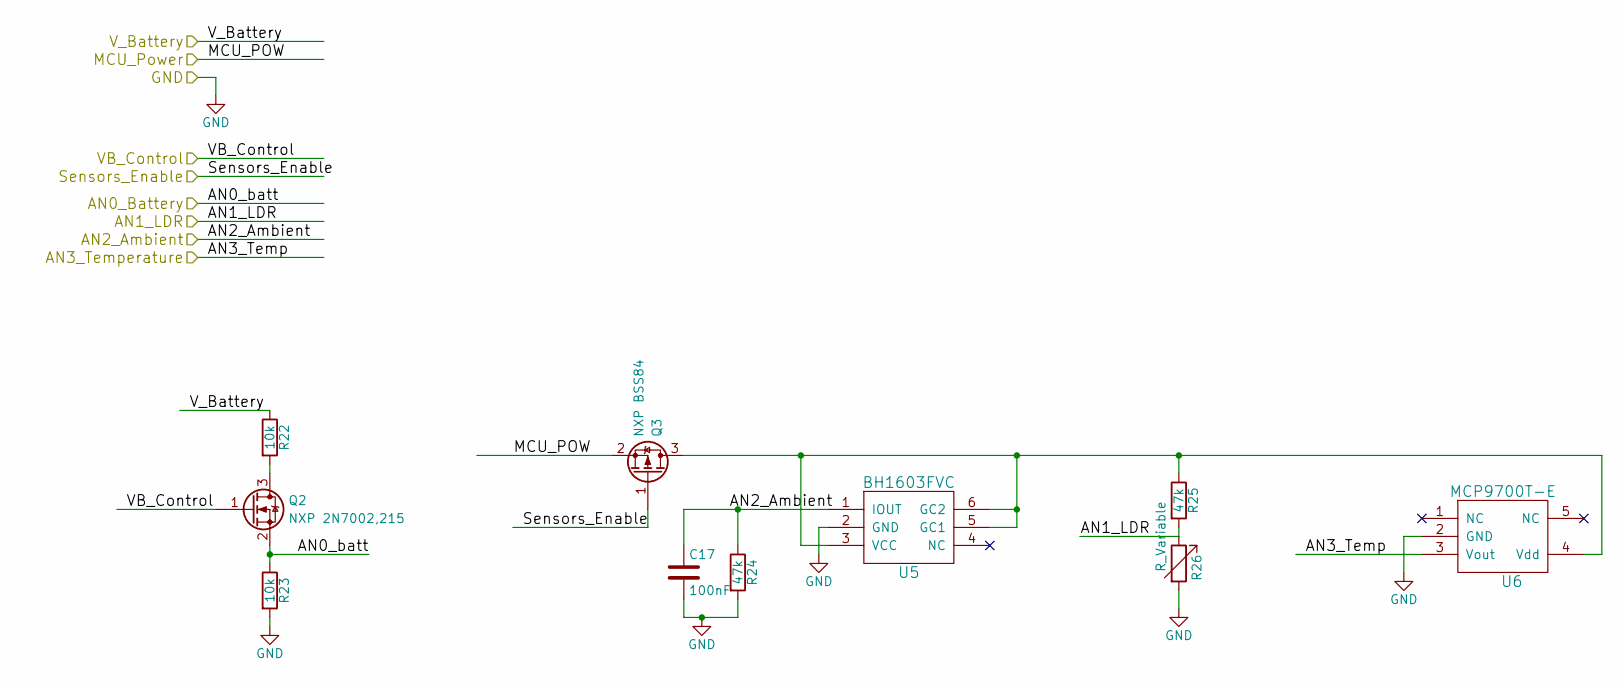
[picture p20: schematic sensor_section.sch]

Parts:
C17: 100nF; C_0805
Q2: NXP 2N7002,215; SOT-23
Q3: NXP BSS84; SOT-23
R22, R23: 10k; R_0805
R24, R25: 47k; R_0805
R26: R_Variable; R_Axial_DIN0204_L3.6mm_D1.6mm_P2.54mm_Vertical
U5: BH1603FVC
U6: MCP9700T-E; SOT-23-5

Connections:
/microcontroller/AN0_Battery: Q2.2 (S), R23.1; also elsewhere on the board
/microcontroller/AN1_LDR: R25.2, R26.1; also elsewhere on the board
/microcontroller/AN2_Ambient: C17.1, R24.1, U5.1 (IOUT); also elsewhere on the board
/microcontroller/AN3_Temperature: U6.3 (Vout); also elsewhere on the board
/microcontroller/MCU_Power: Q3.2 (S); also elsewhere on the board
/microcontroller/Sensors_Enable: Q3.1 (G); also elsewhere on the board
/microcontroller/VB_Control: Q2.1 (G); also elsewhere on the board
GND: C17.2, R23.2, R24.2, R26.2, U5.2 (GND), U6.2 (GND); also elsewhere on the board
unnamed: Q2.3 (D), R22.2
unnamed: Q3.3 (D), R25.1, U5.3 (VCC), U5.5 (GC1), U5.6 (GC2), U6.4 (Vdd)

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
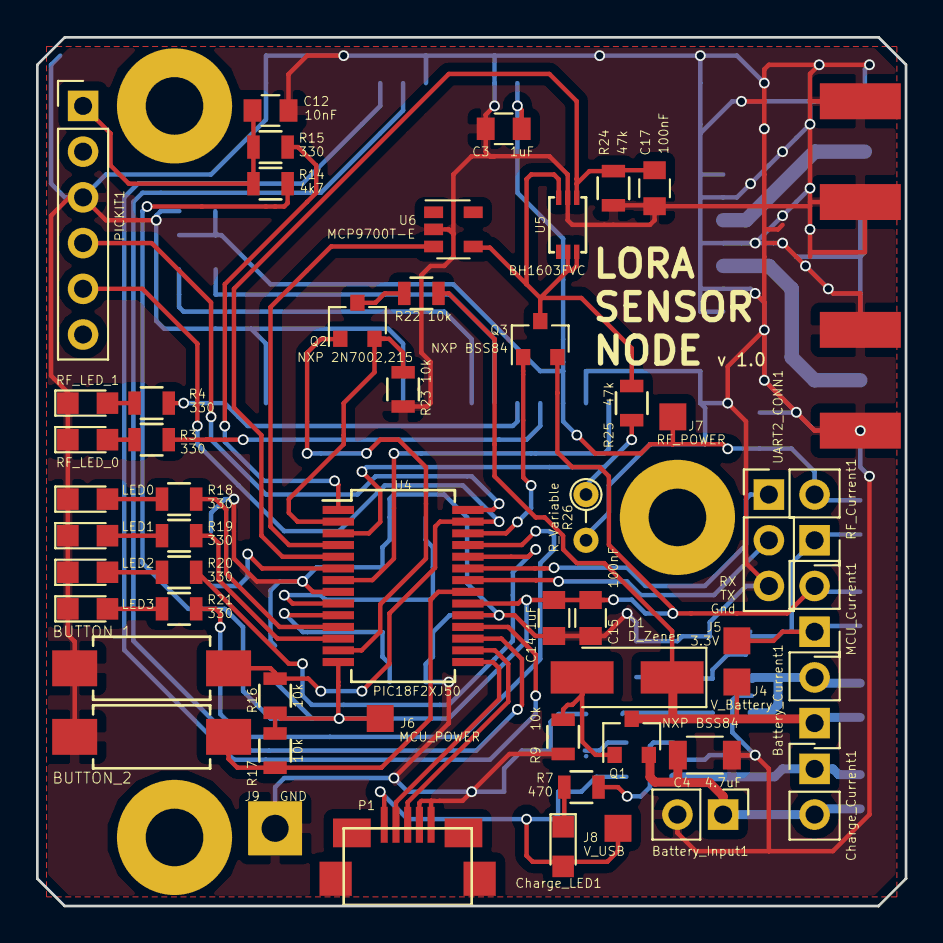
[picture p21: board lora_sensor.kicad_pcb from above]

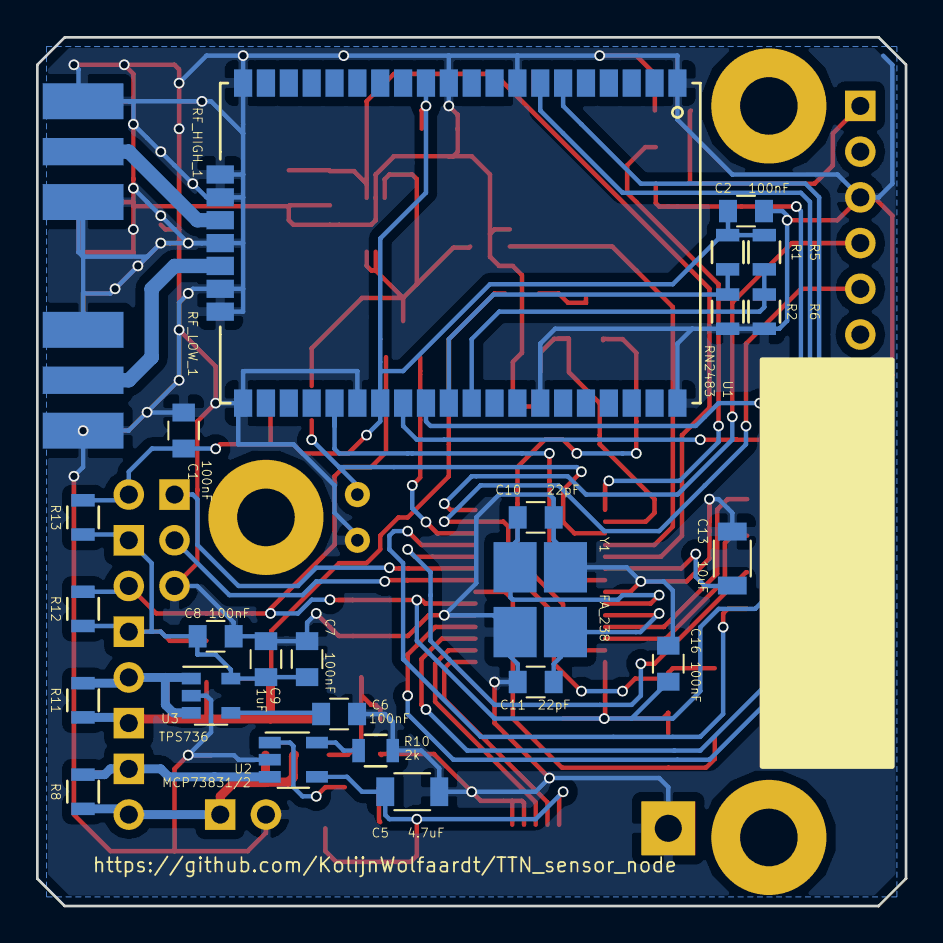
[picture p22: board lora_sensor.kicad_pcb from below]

Board: 2 copper layers, 48.3 x 48.3 mm, 82 parts (26 on the bottom side), 53 nets.

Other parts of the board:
Charge_LED1: LED; LED_0805

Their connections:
/microcontroller/V_USB: Charge_LED1.2; also elsewhere on the board
unnamed 36: Charge_LED1.1; also elsewhere on the board

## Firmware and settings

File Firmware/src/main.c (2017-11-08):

/*
 * File:   newmain.c
 * Author: kolijn
 *
 * Created on 10 April 2017, 9:45 PM
 */
#include <stdio.h>
#include <string.h>

#include <xc.h>
#include "usb.h"
#include "analog.h"
#include "usb_config.h"
#include "usb_ch9.h"
#include "usb_cdc.h"
#include "config_bits.h"
#include "timer.h"
#include "uart.h"
#include "rtc.h"
#include "hardware_init.h"

#ifdef MULTI_CLASS_DEVICE
static uint8_t cdc_interfaces[] = { 0 };
#endif
char HEX_LOOKUP[] = {'0', '1', '2', '3', '4','5','6','7','8','9','A','B','C','D','E','F'};

// Constants that
char TRANSMIT_STRING[] = "mac tx uncnf 1 00000000\r\n";
char TRANSMIT_STR_LEN = 25;
char MAC_STATUS_STRING[] = "mac get status\r\n";
char MAC_STATUS_STR_LEN = 16;
char MAC_JOIN_STRING[] = "mac join abp\r\n";
char MAC_JOIN_STR_LEN = 14;
char RADIO_SLEEP_STRING[] = "sys sleep 1000\r\n";
char RADIO_SLEEP_STR_LEN = 17;
char MAC_CONFIG_STRING[] = "mac set dr 5\r\n";
char MAC_CONFIG_STR_LEN = 14;

//Possible response
char RESPONSE_INVALID[] = "invalid_param";
char RESPONSE_INVALID_LEN = 13;
char RESPONSE_OK[] = "ok";
char RESPONSE_OK_LEN = 2;
char RESPONSE_TX_OK[] = "mac_tx_ok";
char RESPONSE_TX_OK_LEN = 9;

int usb_counter = 0;
int usb_read_pos = 0;
char usb_buffer[256];

// Sensor values
int battery_voltage = 0;
int ldr_value = 0;
int temp_sens = 0;
int light_sensor = 0;

extern states_t CURRENT_STATE;

void reset_radio();
void turn_on_radio();
void add_atoi_to_usb(int num);
void sample_sensor_values();
void update_mac_status();
void send_values();
void sleep_radio();
int receive_value_matches();
int message_matches(char response_string[], int string_length);

char uart_message_buffer[16];

static void send_string_sync(uint8_t endpoint, const char *str)
{
	char *in_buf = (char*) usb_get_in_buffer(endpoint);

	while (usb_in_endpoint_busy(endpoint));

	strcpy(in_buf, str);
	/* Hack: Get the length from strlen(). This is inefficient, but it's
	 * just a demo. strlen()'s return excludes the terminating NULL. */
	usb_send_in_buffer(endpoint, strlen(in_buf));
}

int main(void)
{
    CURRENT_STATE = STARTUP;
    
    int counter = 0;
    // Load the settings from the sleep registers    
    if (CURRENT_STATE == STARTUP)
    {
        // Set up oscillators
        oscillator_init();

        // Set up peripherals like uart
        hardware_setup();
        // usb_init();
        
        setup_adc();
        setup_timer_0();
        
        led_write_num(0xF);
        delayms(3000);
        led_write_num(0x0);
                
        CURRENT_STATE = FIRST_RUN;
        // init_rtc();
        
        //SENSORS_ENABLE = 0;
    }
    
    RCONbits.IPEN = 1; // Enable priority on interrupts
    INTCONbits.GIE = 1; //Enable all interrupts
    INTCONbits.PEIE = 1; // Enable all peripheral interrupts
    
    
    SENSORS_ENABLE = 1;   
    
    while(1)
    {  
        int response_length = 0;
        
        led_write_num(CURRENT_STATE);

        if (CURRENT_STATE == FIRST_RUN)
        {
            // Not much here, just need to reset the radio
            CURRENT_STATE = RESET_RADIO;   
        }
        else if (CURRENT_STATE == WAKE_UP_RADIO)
        {
            // Re-sync the radio with a U character
            // This will also bring it out of sleep if it was
            //LED3 = 1;
            SENSORS_ENABLE = 0;
            turn_on_radio();
            delayms(1000);
            clear_message();
            CURRENT_STATE = GET_MAC_STATUS;
        }
        else if (CURRENT_STATE == GET_MAC_STATUS)
        {
            // Send a get mac status message. This is a special case, as the response should be parsed.
            response_length = send_and_wait(MAC_STATUS_STRING, MAC_STATUS_STR_LEN, 500);   

            if (response_length == -1)
            {
                CURRENT_STATE = HANDLE_ISSUE;
            }
            else
            {
                if (message_matches(RESPONSE_INVALID, RESPONSE_INVALID_LEN))
                {
                    CURRENT_STATE = HANDLE_ISSUE;
                    clear_message();
                }
                else
                {
                    // It was a valid message, and can be parsed
                    update_mac_status();
                    if (mac_state.join_status == 1)
                        CURRENT_STATE = SET_DR_VALUE;
                    else
                        CURRENT_STATE = JOIN_NETWORK;
                    clear_message();
                }
            }
        }
        else if (CURRENT_STATE == JOIN_NETWORK)
        {
            response_length = send_and_wait(MAC_JOIN_STRING, MAC_JOIN_STR_LEN, 500);

            if (response_length == -1)
            {
                CURRENT_STATE = HANDLE_ISSUE;
                clear_message();
            }
            else 
            {
                if (message_matches(RESPONSE_OK, RESPONSE_OK_LEN))
                {
                    // Wait for the accepted message
                    CURRENT_STATE = SET_DR_VALUE;
                    clear_message();
                }
                else
                {
                    CURRENT_STATE = HANDLE_ISSUE;
                    clear_message();
                }
            }
        }
        else if (CURRENT_STATE == SET_DR_VALUE)
        {
            response_length = send_and_wait(MAC_CONFIG_STRING, MAC_CONFIG_STR_LEN, 500);
            
            if (response_length == -1)
            {
                CURRENT_STATE = HANDLE_ISSUE;
            }
            else
            {
                if (message_matches(RESPONSE_OK, RESPONSE_OK_LEN)) 
                {
                    CURRENT_STATE = SEND_VALUES;
                    clear_message();
                }
                else
                {
                    CURRENT_STATE = HANDLE_ISSUE;
                    clear_message();
                }
            }
        }
        else if (CURRENT_STATE == SEND_VALUES)
        {
            sample_sensor_values();
            response_length = send_and_wait(TRANSMIT_STRING, TRANSMIT_STR_LEN, 500);

            if (response_length == -1)
            {
                CURRENT_STATE = HANDLE_ISSUE;
            }
            else
            {
                if (message_matches(RESPONSE_OK, RESPONSE_OK_LEN)) 
                {
                    CURRENT_STATE = GOTO_SLEEP;
                }
                else
                {
                    CURRENT_STATE = HANDLE_ISSUE;
                }
            }
        }
        else if (CURRENT_STATE == SEND_VALUES_RESPONSE)
        {
            // We are receiving the ok and mac_tx_ok directly after
            //each other , making it difficult to parse. For now, skip this step.
            //Wait for the secondary response
            uart1_wait_for_message(5000);

            if (message_matches(RESPONSE_TX_OK, RESPONSE_TX_OK_LEN)) 
            {
                CURRENT_STATE = GOTO_SLEEP;
            }
            else
            {
                // Why are we getting double 'ok' s?
                if (message_matches(RESPONSE_OK, RESPONSE_OK_LEN))
                {
                    CURRENT_STATE = GOTO_SLEEP;
                }
                else
                {
                    CURRENT_STATE = HANDLE_ISSUE;
                    //CURRENT_STATE = GOTO_SLEEP;
                }
            }
        }
        else if (CURRENT_STATE == GOTO_SLEEP)
        {
            clear_message();
            uart_send_message(RADIO_SLEEP_STRING, RADIO_SLEEP_STR_LEN, UART1);
            CURRENT_STATE = SLEEP;
            //LED3 = 0;
        }
        else if (CURRENT_STATE == SLEEP)
        {
            
            SENSORS_ENABLE = 1;
            // We have received an 'ok' from the radio, go to sleep
//            DSWAKEL = CURRENT_STATE;
//            WDTCONbits.REGSLP = 1;
//            OSCCONbits.IDLEN = 1;
//            while (RTCCFGbits.RTCSYNC == 1);
//            DSCONHbits.DSEN = 1;
//            asm("sleep");
            delayms(1000);
            delayms(1000);
            delayms(1000);
            delayms(1000);
            delayms(1000);
            CURRENT_STATE = WAKE_UP_RADIO;
            
        }
        else if (CURRENT_STATE == HANDLE_ISSUE)
        {
            // This will really depend on the issue. For now just reset,
            // And hope that that solves it
            //add_buffer_to_usb("Error, restarting\r\n", 19);
            CURRENT_STATE = RESET_RADIO;
        }
        else if (CURRENT_STATE == RESET_RADIO)
        {
            RADIO_RESET = 0;
            delayms(100);
            RADIO_RESET= 1;
            CURRENT_STATE = WAKE_UP_RADIO;
        }
        
        // Sends a message to the PC 
        if (usb_is_configured() && !usb_in_endpoint_halted(2) && !usb_in_endpoint_busy(2))
        {
            if (usb_counter != 0)
            {
                int i;
                unsigned char *buf = usb_get_in_buffer(2);
                
                if (usb_counter - usb_read_pos> 64)
                {
                    for (i=0; i < 64; i++)
                    {
                        buf[i] = usb_buffer[usb_read_pos+i];
                    }
                    usb_read_pos += 64;
                }
                else
                {
                    for (i=0; i < usb_counter - usb_read_pos; i++)
                    {
                        buf[i] = usb_buffer[usb_read_pos+i];
                    }
                    usb_read_pos = usb_counter;
                }

                usb_send_in_buffer(2, i);
                
                if (usb_counter == usb_read_pos)
                {  
                    usb_counter = 0;
                    usb_read_pos = 0;
                }
            }
        }
        
        // Handle data received from the host 
		if (usb_is_configured() && !usb_out_endpoint_halted(2) && usb_out_endpoint_has_data(2))
        {
			const unsigned char *out_buf;
			size_t out_buf_len;

			// Check for an empty transaction. 
			out_buf_len = usb_get_out_buffer(2, &out_buf);
			usb_arm_out_endpoint(2);
		}
        
        #ifndef USB_USE_INTERRUPTS
        usb_service();
		#endif
    }
}


void reset_radio()
{
    // Make the TX pin a output
    TXSTA1bits.TXEN = 0;
    TRISCbits.TRISC6 = 0;
    LATCbits.LATC6 = 0;
    
    // Small Delay
    delayms(20);
    
    // Re-enable the transmitter
    TXSTA1bits.TXEN = 1;
    char temp_buffer[] = {0x55};
    uart_send_message(temp_buffer,1, UART1);
    while (uart1_busy() != true);
    clear_message();
}


void turn_on_radio()
{    
    // Awaken! Awaken!
    reset_radio();
//    add_char_to_usb('\r');
//    add_char_to_usb('\n');
    
    // Send some blank lines to clear the buffer
    uart_send_message("\r\n", 2, UART1);
    delayms(200);
    
    // Clear any possible message that might have been received
    clear_message();
}


void update_mac_status()
{
    // Check that the received message is long enough
    if (uart1_rx_buf_write_pos > 4){
        mac_state.join_status = 0;
    }
}


void sample_sensor_values()
{
//    add_buffer_to_usb("Sampling ADC values\r\n", 21);
    // Wait for the values to stabilize    
    battery_voltage = sample_value(BATTERY);
    ldr_value = sample_value(LDR);
    temp_sens = sample_value(TEMPERATURE);   
    light_sensor = sample_value(AMBIENT);
        
    TRANSMIT_STRING[15] = HEX_LOOKUP[(battery_voltage>>12) & 0xF];
    TRANSMIT_STRING[16] = HEX_LOOKUP[(battery_voltage>>8) & 0xF];
    TRANSMIT_STRING[17] = HEX_LOOKUP[(battery_voltage>>4) & 0xF];
    TRANSMIT_STRING[18] = HEX_LOOKUP[battery_voltage & 0xF];
    TRANSMIT_STRING[19] = HEX_LOOKUP[(temp_sens>>12) & 0xF];
    TRANSMIT_STRING[20] = HEX_LOOKUP[(temp_sens>>8) & 0xF];
    TRANSMIT_STRING[21] = HEX_LOOKUP[(temp_sens>>4) & 0xF];
    TRANSMIT_STRING[22] = HEX_LOOKUP[temp_sens & 0xF];
    
    // uart_send_message(TRANSMIT_STRING, 24, UART2);
}

interrupt high_priority void high_isr() {
#ifdef USB_USE_INTERRUPTS
    usb_service();
#endif

    if (INTCONbits.TMR0IF == 1) {
        timer_0_callback();
        INTCONbits.TMR0IF = 0;
    }
    if (PIR3bits.RTCCIF == 1) {
        rtc_interrupt();
        PIR3bits.RTCCIF = 0;
    }
    if (PIR1bits.TX1IF == 1) {
        uart_1_tx_interrupt();
    }
    if (PIR1bits.RC1IF == 1) {
        uart_1_rx_interrupt();
        PIR1bits.RC1IF = 0;
    }
    if (PIR3bits.TX2IF == 1) {
        uart_2_tx_interrupt();
    }
    if (PIR3bits.RC2IF == 1) {
        uart_2_rx_interrupt();
        PIR3bits.RC2IF = 0;
    }
}


void add_char_to_usb(char data)
{
    usb_buffer[usb_counter] = data;
    usb_counter++;
    if (usb_counter == 512)
    {
        usb_counter = 0;
    }
}

void add_buffer_to_usb(char buffer[], int length)
{
    int i = 0;
    for (i=0; i<length; i++)
    {
        usb_buffer[usb_counter] = buffer[i];
        usb_counter++;
    }
}

void add_atoi_to_usb(int num)
{
    char aString[4];

    // convert 123 to string [buf]
    
    aString[0] = (num/1000 % 10) + 0x30;
    aString[1] = (num/100 % 10) + 0x30;
    aString[2] = (num/10 % 10) + 0x30;
    aString[3] = (num % 10)  + 0x30;
    
    add_buffer_to_usb(aString, 4);
}

int message_matches(char response_string[], int string_length)
{
    // check that the received string is long enough
    if (uart1_rx_buf_write_pos < string_length)
    {
        return 0;
    }
    
    int i = 0;
    char matches = 1;
    for (i = 0; i < string_length; i++) {
        if (response_string[i] != uart_1_rx_buffer[i])
        {
            matches = 0;
        }
    }
    return matches;
}

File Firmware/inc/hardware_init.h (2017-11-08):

/* 
 * File:   hardware_init.h
 * Author: kolijn
 *
 * Created on 20 April 2017, 6:48 AM
 */

#include <xc.h>

#ifndef HARDWARE_INIT_H
#define	HARDWARE_INIT_H

#ifdef	__cplusplus
extern "C" {
#endif

void oscillator_init(void);
void hardware_setup(void);
void led_write_num(int num);
void add_char_to_usb(char data);
void add_buffer_to_usb(char buffer[], int length);

#define LED0 LATCbits.LATC0
#define LED1 LATCbits.LATC1
#define LED2 LATBbits.LATB3
#define LED3 LATBbits.LATB4

#define BAT_SENS_DISABLE LATCbits.LATC2
#define SENSORS_ENABLE LATBbits.LATB5

#define BUTTON0 PORTBbits.RB0
#define BUTTON1 PORTBbits.RB6

#define RADIO_RESET LATAbits.LATA5

typedef enum  
{
    STARTUP=1,
    INIT_HARDWARE=2,
    FIRST_RUN=3,
    WAKE_UP_RADIO=4,
    GET_MAC_STATUS=5,
    JOIN_NETWORK=6,
    SET_DR_VALUE=7,
    SEND_VALUES=8,
    SEND_VALUES_RESPONSE=9,
    GOTO_SLEEP=10,
    SLEEP=0,
    HANDLE_ISSUE=14,
    RESET_RADIO=15,
}states_t;

states_t CURRENT_STATE = STARTUP;

struct {
    unsigned int join_status : 1;
    unsigned int mac_state : 3;
} mac_state;

#ifdef	__cplusplus
}
#endif

#endif	/* HARDWARE_INIT_H */

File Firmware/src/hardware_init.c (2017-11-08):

#include <xc.h>
#include "hardware_init.h"
#include "uart.h"

void oscillator_init(void);
void hardware_setup(void);
void setup_uart_1(void);
void led_write_num(int num);

void oscillator_init(void)
{
    unsigned int pll_startup = 600;
	OSCTUNEbits.PLLEN = 1;
	while (pll_startup--);
    
    INTCONbits.PEIE = 1;
    INTCONbits.GIE = 1;
}

void hardware_setup(void)
{
    // Setup LED pins as Outputs
    TRISCbits.TRISC0 = 0;
    TRISCbits.TRISC1 = 0;
    TRISBbits.TRISB3 = 0;
    TRISBbits.TRISB4 = 0;
    
    // Setup the Buttons as inputs
    TRISBbits.TRISB0 = 1;
    TRISBbits.TRISB6 = 1;
    
    // Set sensor enable pin as output
    TRISBbits.TRISB5 = 0;
    
    // disable analog on LED pin
    ANCON1bits.PCFG9 = 0x1;
    
    // disable analog on button pin
    ANCON1bits.PCFG12 = 0x1;
    
    // Setup uart 1 - for communicating with the radio IC
    setup_uart_1();
    setup_uart_2();
    
    // Set the radio Reset pin
    TRISAbits.TRISA5 = 0;
    ANCON0bits.PCFG4 = 0x1;
    RADIO_RESET = 1;
    
    // Set the analog pins tris bits to input
    TRISAbits.TRISA0 = 1;
    TRISAbits.TRISA1 = 1;
    TRISAbits.TRISA2 = 1;
    TRISAbits.TRISA3 = 1;
    ANCON0bits.PCFG0 = 0;
    ANCON0bits.PCFG1 = 0;
    ANCON0bits.PCFG2 = 0;
    ANCON0bits.PCFG3 = 0;
    
        
    led_write_num(0);
}

void led_write_num(int num)
{
    LED0 = (num) & 0x1;
    LED1 = (num >> 1) & 0x1;
    LED2 = (num >> 2) & 0x1;
    LED3 = (num >> 3) & 0x1;
}

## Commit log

2017-02-05 Added basic PCB layout
    [_saved_lora_sensor.sch, lora_sensor.kicad_pcb, lora_sensor.sch]
2017-02-05 Updates Schematic
    [_saved_lora_sensor.sch, lora_sensor.sch]
2017-02-06 Improved schematic, updated component-module mappings
    [lora_sensor.sch, lora_sensor_bom.csv, microcontroller.sch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]
2017-02-07 More modules, initial pcb layout
    [lora_sensor_bom.csv, microcontroller.sch, power_section.sch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]
2017-02-12 Added PCB LAyout
    [lora_sensor.kicad_pcb, lora_sensor.sch, microcontroller.sch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]
2017-02-12 Finalized layout, added gerbers and renders
    [lora_sensor-B.Cu.gbr, lora_sensor-B.Mask.gbr, lora_sensor-B.SilkS.gbr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]
2017-02-13 Small layout improvements
    [lora_sensor.kicad_pcb]
2017-02-13 More layout updates
    [lora_sensor.kicad_pcb, power_section.sch]
2017-07-01 Manufactured version
    [lora_sensor.kicad_pcb, lora_sensor_bom.csv, power_section.sch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]
2017-07-01 Moved pcb layout folder
    [lora_sensor-B.Cu.gbr, lora_sensor-B.Mask.gbr, lora_sensor-B.SilkS.gbr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]
2017-07-01 Adds firmware, currently transmitting every minute
2017-07-02 Fix images. Resized manually, added different board photo
2017-11-08 Firmware works without periodic crashes
    [analog.c, hardware_init.c, hardware_init.h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]
2017-11-08 Updated libraries to newer version
    [lora_sensor.sch, microcontroller.sch, power_section.sch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]
